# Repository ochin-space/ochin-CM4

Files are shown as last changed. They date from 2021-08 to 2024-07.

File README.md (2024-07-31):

ochin_CM4
# ochin_CM4
The öchìn CM4 it’s a tiny carrier board for the Raspberry Pi Compute Module  It is designed for applications where a powerful machine with low consumption and small dimensions is required. The small form factor makes it interesting for all those applications where the space available is not much and containing the weight is important, such as in robotics, home automation and IOT.
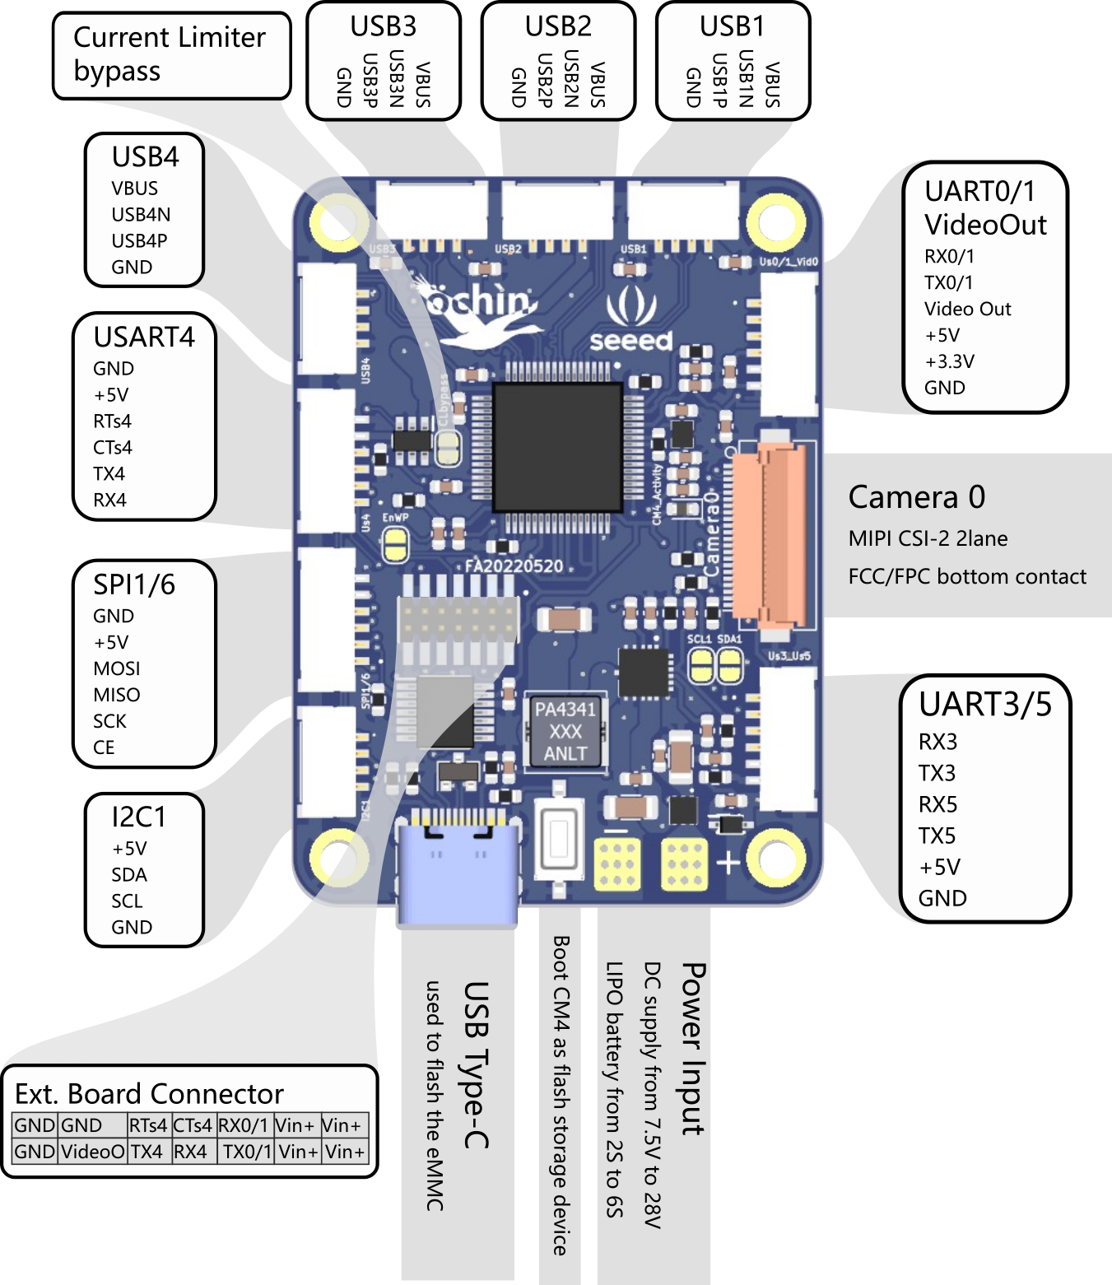
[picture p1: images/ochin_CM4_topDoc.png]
ochin_CM4

The board is compatible with all Raspberry Pi CM4 modules equipped with eMMC. Depending on your needs, you can select a CM4 module with an SDRAM starting from 1GB up to 8GB and the eMMC from 8GB up to 32GB, with or without the Wi-Fi / BT4 connection.

Key features of the Raspberry Pi CM4 available on öchìn are as follows:
* Broadcom BCM2711, Quad core Cortex-A72 (ARM v8) 64-bit SoC @ 1.5GHz
* Small Footprint 55mm × 40mm × 4.7mm module
* H.265 (HEVC) (up to 4Kp60 decode), H.264 (up to 1080p60 decode, 1080p30 encode)
* OpenGL ES 3.0 graphics
* Options for 1GB, 2GB, 4GB or 8GB LPDDR4-3200 SDRAM with ECC
* Options for 8GB, 16GB, or 32GB eMMC Flash
o Peak eMMC bandwidth 100MBytes/s
o 2.4 GHz, 5.0 GHz IEEE 802.11 b/g/n/ac wireless
o Bluetooth 5.0, BLE
o On board electronic switch to select between PCB trace or external antenna
* 1×USB 2.0 port (highspeed)
* MIPI CSI-2:
o 1×2-lane MIPI CSI camera port, 1×4-lane MIPI CSI camera port
* 1×USART, 3×UART, 1×I2C port, 1×SPI port, Analog Video Output

In this repository you can find the manual of the board, a quick start guide for flashing the CM4 module and a guide with some tips on how to make the connections to the ochin board. 

It is important to read them both before turning on the ochin_CM4 board, to know its characteristics and above all the sequence in which the signals are present on the connectors.

# Community

Feel free to join the öchìn CM4 [Discord](https://discord.gg/Uj9XfSwn) group with members helping each other.

# Where to buy the ochin_CM4 boards
The ochin_CM4 boards are manufactured and sold by Seeedstudio. You can purchase ochin_CM4 boards from Seeedstudio's marketplace, https://www.seeedstudio.com or from Seeedstudio's business partners (Digikey, Mouser, RS components and many others).

# License Notice for This GitHub Repository

This GitHub repository contains various resources that are subject to specific licenses. Please note the following information regarding the applicable licenses:

* Documentation, Manuals, PDF Schematics, scripts and Other Textual Content: All textual documents present in this repository, including manuals, schematics, and documentation, are released under the GNU Free Documentation License (GFDL).

* Hardware (KiCad Sources, Gerber Files, Assembly Files, etc.): The hardware-related items, including but not limited to KiCad sources, Gerber files, and assembly files, are subject to a proprietary license. This means that these resources are not released as open source and their use is governed by the terms specified in the accompanying documentation or separate terms of use provided.

Please respect the conditions of both licenses when using and distributing the materials in this repository.

For any questions or clarifications regarding the licenses, feel free to contact us.

# Important!!!

The ochin_CM4 board must be used with a Raspberry Pi CM4 module with eMMC (the lite version is not good), there is no slot for the microsd card onboard. The reasons for this choice are explained in the manual and concern the optimization of spaces and the efficiency of the internal flash.

Print and use the extractor for the CM4 module if you don't want to break the mezzanines, you can find the .stl in the "3d/Covers turrets and extractors" section of this repository.

Take a look at the "öchìn CM4 - Wiring and Suggestions.pdf" before power the board on, it may save your time and your devices.

Never trust the color code of the GHS cables, the sequence in which commercial GHS cables are assembled is often random and does not reflect the sequence of the signals present in the connectors of the ochin_CM4 board.

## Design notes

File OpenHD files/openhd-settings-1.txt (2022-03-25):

#!/bin/bash
#
# ======================================================================================
#    <BASIC RF/VIDEO LINK CONFIGURATION>
# ======================================================================================

# >>>>>>>>>>[FREQUENCY FOR OPEN.HD]-- in MHz (See full Frequency List Below)
# By default the frequency will be chosen automatically for the hardware you have connected to your ground/air pi,
# but if you want to set a frequency manually, make sure it is supported by your hardware. Atheros cards are 2.4Ghz only
# and Realtek 8812/14 cards are only stable on 5.8Ghz. Frequencies are listed at the bottom of this file
FREQ=5320

# >>>>>>>>>>[DATARATE] Lower settings yield higher range and vice versa.  
# Below are the datarate settings for Legacy B/G and MCS "N" modes. 
DATARATE=3

# 1 - 5.5   =    802.11b         1 - 6.5   =     MCS 0
# 2 - 11    =    802.11b         2 - 13    =     MCS 1
# 3 - 12    =    802.11g         3 - 13    =     MCS 1
# 4 - 19.5  =    802.11n         4 - 19.5  =     MCS 2
# 5 - 24    =    802.11g         5 - 26    =     MCS 3           
# 6 - 36    =    802.11g         6 - 39    =     MCS 4

# # >>>>>>>>>>[MCS ; Space Time Block Coding ; Low Density Parity Check]
# Only tested MCS+STBC+LDPC with RTL8812AU cards. MCS=Y only should work with Atheros cards when STBC/LDPC=N 
UseMCS=N
UseSTBC=N
UseLDPC=N

# # >>>>>>>>>>[IP/USB CAMERA SECONDARY DATA RATES]
# Applied only to 8812AU with 2nd IP/USB cam, all other setups, ignore! Ath9k will ignore secondary camera datarate and use DATARATE=
# 0=6.5Mbit (BPSK 1\2),		1=13Mbit (QPSK 1\2)
# 2= 19.5MBit (QPSK 3/4), 	3=26Mbit (16-QAM 1\2)
DATARATE_SECONDARY_8812AU=2

# >>>>>>>>>>[TXPOWER-AIR/GROUND]-- For Atheros AR9271 or RTL8812/14AU Cards ONLY
TxPowerAir=58
TxPowerGround=58

# >>>>>>>>>>[TXPOWER-RALINK]-- (Not confirmed Working]
TXPOWER=2000

# >>>>>>>>>>[FEC (FORWARD ERROR CORRECTION)]-- (8/4/1024 default) 
# *For higher bitrate and range, you can reduce FEC to "2" for example by setting (10/2/1024)
# max. blocklength Ralink = 2278, Atheros = 1550
# min. sensible blocklength ~ 700
VIDEO_BLOCKS=8
VIDEO_FECS=4
VIDEO_BLOCKLENGTH=1024

#Secondary camera (IP\USB)
VIDEO_BLOCKS_SECONDARY=8
VIDEO_FECS_SECONDARY=4

# >>>>>>>>>>[DEBUGGING OR SSH]--
# Set this to "Y" to enable collection of extra debug logs or to allow SSH. If you experience anyways
# issues. "Y" also turns on the display for the airpi
DEBUG=N

# >>>>>>>>>>[DISABLE SCREEN MESSAGES]--
# Set this to "Y" to disable text messages about Display and Wifi card setup etc.
QUIET=N

# >>>>>>>>>>[SCREENSHOTS]--
# Set to "Y" to enable periodic screenshots every 10 seconds
ENABLE_SCREENSHOTS=N

# >>>>>>>>>>[DISABLE OSD]--
# Set to "Y" to enable ground OSD. set "N" to only display video. 
DISPLAY_OSD=Y

# set to "Y" to use the QOpenHD app instead of the original OSD
ENABLE_QOPENHD=N

# >>>>>>>>>>[5/10/20Mhz BANDWIDTH SETTINGS]--Default 20mhz
# !!!!!!! ATHEROS CARDS ONLY  !!!!!!!!!!!!!!!!!!!!!
# Users can choose between 20mhz, 10mhz or 5mhz bandwidth at the expense of 1/4 or 1/2 of total available 
# Datarate/Bitrate. Range can be increased significantly with 5/10mhz "Narrowband".
# ***Default @ 20mhz compatible with all Wireless cards. 5/10mhz Bandwidth options will result in
# Bandwidth:5, 10 or 20.
Bandwidth=20

# ======================================================================================
#                            <VIDEO/CAMERA CONFIGURATION>
# ======================================================================================

# >>>>>>>>>>[VIDEO BITRATE]-- "auto" recommended
# Air Pi reads available bandwidth to determine bitrate.
# 
# Set to a fixed value to disable automatic measuring 
# 
# Note: the unit for this setting is megabits, not kilobits or bits!
# For 4.5mbit, set to 4.5
VIDEO_BITRATE=auto

# >>>>>>>>>>[BITRATE PERCENTAGE]-- "65 default"
# Depending on channel utilization by other wifi networks you may need to set
# this to a lower value like 60% to avoid a delayed video stream.
# On free channels you may set this to a higher value like 75% to get a higher
# bitrate and thus image quality.
BITRATE_PERCENT=50

# >>>>>>>>>>[CAMERA RESOLUTION]--
# V1 cam: 1280x720: 30fps, 48fps. 1920x1080: 30fps
# V2 cam: 1280x720: 30fps, 48fps, 59.9fps. 1640x922: 30fps, 40fps. 1920x1080: 30fps
WIDTH=1280
HEIGHT=720

# >>>>>>>>>>[CAMERA FPS]--"48 default"
# Choose between 30, 40, 48, 59.9, values above 60 are experimental
FPS=30

# >>>>>>>>>>[KEYFRAME RATE]-- 
# ***This is how often a "fresh-new" video frame is transmitted***
# Lower values mean faster glitch-recovery, but also lower video quality.
# With fps=48 and keyframerate=5, glitches will stay visible for around 100ms in worst case.
# You can set this higher or lower according to your needs. Minimum value is 2.
KEYFRAMERATE=10
#
# >>>>>>>>>>[RASPIVID CAMERA SETTINGS]--
# There are dozens of paramaters, see the RPI forum for all settings.
EXTRAPARAMS="-cd H264 -n -fl -ih -pf high -if both -ex sports -mm average -awb horizon"
# UNCOMMENT, AND USE THESE CAMERA SETTINGS FOR THE B101 OR SIMILAR HDMI-CSI ADAPTER
#EXTRAPARAMS="-cd H264 -n -fl -ih -pf high -if both"

# >>>>>>>>>>[SAVE VIDEO-RAMdisk/Memory]--Set to "memory" to use RAMdisk for temporary video/screenshot/telemetry 
# storage recording time to ~12-14 minutes, but is the safe way. If you need longer recording times, use "sdcard", to 
# use the sdcard as the temporary video storage. Keep in mind though, that this might introduce video stutter and/or bad blocks. 
# you can also disable recording entirely by setting VIDEO_TMP=none
VIDEO_TMP=memory

# >>>>>>>>>>[Use openhdvid instead of raspivid]
# Raspivid is the default and stable option, openhdvid is a new replacement for it that will allow live camera
# parameter changes and other enhancements. It is not well tested yet.
ENABLE_OPENHDVID=N

# >>>>>>>>>>[Use new raspberry pi camera AWB algorithm]
# Buster only (strech doesn't have new enough firmware for it)
# This option is here because the new AWB algorithm can cause color tint in certain cases, we're
# disabling it to use the old one by default. The advantage of the newer one is it doesn't shift as
# rapidly when the scene changes.
ENABLE_NEW_PI_AWB=N

# ======================================================================================
#                   <GROUND STATION/PC/PHONE/TABLET INTERFACE CONFIG>
# ======================================================================================

# >>>>>>>>>>[HOTSPOT SOURCE]-- **THE EXTERNAL HOTSPOT IS CURRENTLY BROKEN, DON'T USE**
# Set "internal" or MAC address of EXTERNAL wifi card
WIFI_HOTSPOT_NIC=internal

# >>>>>>>>>>[HOTSPOT MODE]-- Default SSID is "Openhd" Password "wifiopenhd"
# ***USE WITH QGC-PHONE, OPENHD APP, MISSION PLANNER OR HID/RC APP***
# Set "auto" (default) with Pi3b+ as GroundPi (it has 2.4/5ghz internal hotspot) OR Pi3b/2b video is 5.8ghz 
# and internal hotspot is 2.4ghz. For 2.4ghz hotspot and 2.4ghz video must be manually set at your own risk!
# Set "Y" to enable Hotspot and you (manually) set the band & ch below. 
# Set to "N" for no wifi hotspot (Recommended If NOT using Pi3b+ & 2.4ghz for video as it could # interfere.
WIFI_HOTSPOT=N

# >>>>>>>>>>[HOTSPOT BAND/CHANNEL_MANUAL CONFIG]
# NOTE with WIFI_HOTSPOT=auto your setting here will be over written.
# Set to "g" for 2.4ghz , "a" for 5.8ghz, 
# Channels 1-11 for 2.4Ghz, 
# Channels 36,40,44,48,52,56,60,64 for 5Ghz
HOTSPOT_BAND=a
HOTSPOT_CHANNEL=36
# Set to number of seconds you wany hotspot to shutdown. Default is "0", run forever
HOTSPOT_TIMEOUT=0
# hotspot transmit power in units of mBm, so 100 corresponds to 1dBm
# to set full power, use HOTSPOT_TXPOWER=3100
HOTSPOT_TXPOWER=3100

# >>>>>>>>>>[ETHERNET HOTSPOT]--*Only used for PC/Mission Planner Ethernet connection
# Set this to "Y" to enable Ethernet hotspot. This will forward the received video and 
# telemetry to another PC.
ETHERNET_HOTSPOT=N

# >>>>>>>>>>[FORWARD RTP/RAW h.264 VIDEO TO PC/PHONE]
# Set this to "raw" to forward a raw h264 stream to 2nd display devices (for QGC/FPV_VR app)
# Set to "rtp" to forward RTP h264 stream 
FORWARD_STREAM=rtp

# >>>>>>>>>>[UDP PORT SETUP]--
# UDP port to send video stream to, set to 5000 for FPV_VR app or 5600 for Mission Planner/QGC
VIDEO_UDP_PORT=5600
# *EXPERIMENTAL* Secondary IP/USB Camera UDP Port (DON'T CHANGE)
VIDEO_UDP_PORT2=5601

# ======================================================================================
#                     <TELEMETRY/USB RC CONFIGURATION>
# ======================================================================================

# >>>>>>>>>>[CTS PROTECTION]--Use in areas with other wifi networks or Interference
# Set "Y" in conjunction with ATHEROS "Range" RC
# Set "auto" for automatic detection. 
# Set "N" to disable.
CTS_PROTECTION=N

# >>>>>>>>>>[USB RC RANGE OR ENCRYPTION]-- 
# For Atheros AND RTL8812AU Cards use "Range".
# For any other cards use "Encryption" + CTS=N (NOT TESTED VERY MUCH)
# ***"Range" Uses the original EZ-wifibroadcast "joystick" code. This setting should provide better range. 

# ***"Encryption" Is a more secure means of RC uplink and works with any wifi cards but may
# Result in higher packet loss at longer ranges.
EncryptionOrRange=Range

# >>>>>>>>>>[RC JOYSTICK MODE OVER OPEN.HD SETTINGS]
# Set this to "mavlink" to enable R/C over Open.HD using mavlink protocol or "msp" for MSP
# protocol.
# Set to "sumd" for Graupner SUMD, "ibus" for Flysky IBUS, "srxl" for Multiplex SRXL/XBUS
# Mode B. Set to "disabled" to disable
# **See joyconfig.txt for other settings, default settings work for Taranis in USB.
RC=ibus

# >>>>>>>>>>[DEDICATED WIFI-CARD UPLINK/RC MAC ADDR.]-- If different types of Ground wifi cards are used.
# Set this if you have 1 High-Power ground card plus 1 or more lower power cards so that
# all uplink is sent using the high-power card. Otherwise, leave "0" and RC/Uplink will
# be automatically selected based on RSSI signal. 
# ***Also Set for Bandwidth Switcher Function (Below)***
#Ground RX card Primary
PrimaryCardMAC=0

# >>>>>>>>>>[TELEMETRY WBC/OTHER]--
# wbc = use wifibroadcast as telemetry up/downlink
# external = use external means as telemetry up/downlink (LRS or 3DR dongles)
# if set to external, set serialport to which LRS or 3DR dongle is connected
# both on ground and air pi
TELEMETRY_TRANSMISSION=wbc

# >>>>>>>>>>[TELEMETRY UPLINK]--
# Set to "disabled" or "mavlink" for Mavlink (QGC, Missionplanner, etc.)
TELEMETRY_UPLINK=mavlink

# >>>>>>>>>>[USB OPENHD-RC SERIAL PORT/BAUDRATE]--Serial Port Settings between Air Pi & Flight Controller.
# Serial port and baudrate (19200 is minimum) 
# Set this to "/dev/serial0" for Pi onboard UART serial port or "/dev/ttyUSB0" for FTDI adapter. 
FC_RC_SERIALPORT=/dev/serial0
FC_RC_BAUDRATE=115200

# >>>>>>>>>>[OPENHD-FC SERIAL PORT/BAUDRATE]-- Air Pi and Flight Controller 
# *Should be the same as FC_RC_BAUDRATE 
FC_TELEMETRY_SERIALPORT=/dev/serial0
FC_TELEMETRY_BAUDRATE=115200

# >>>>>>>>>>[EXTERNAL DEVICE SERIAL PORT BAUDRATE]--Serial port settings if using TELEMETRY_TRANSMISSION=external
EXTERNAL_TELEMETRY_SERIALPORT_GROUND=/dev/serial0
EXTERNAL_TELEMETRY_SERIALPORT_GROUND_BAUDRATE=57600

# >>>>>>>>>>[GROUND SERIAL PORT OUT ENABLE?]--Set to "Y" to enable output of telemetry to serialport on ground Pi
# (for antenna tracker etc.)
ENABLE_SERIAL_TELEMETRY_OUTPUT=N

# >>>>>>>>>>[GROUND SERIAL PORT/BAUDRATE OUT]-- 
# Used for ground Pi telemetry output if TELEMETRY_OUTPUT=Y
TELEMETRY_OUTPUT_SERIALPORT_GROUND=/dev/serial0
TELEMETRY_OUTPUT_SERIALPORT_GROUND_BAUDRATE=57600

# >>>>>>>>>>[Filter Mavlink 2 telemetry for slow trackers]
# This prevents some antenna trackers from being overloaded by extra mavlink messages.
# You should not enable this if you do not use Mavlink or if you are not using an antenna tracker.
TELEMETRY_OUTPUT_SERIALPORT_GROUND_FILTER=N

#  ======================================================================================
#                      <ADVANCED/ADDITIONAL HARDWARE SETTINGS>
#  ======================================================================================

# >>>>>>>>>>[ARDUCAM V2.0 OR V2.1 MULTI-CAMERA ADAPTER]-- 
# This Camera Switcher feature must be used with the Arducam 4 camera Raspberry Pi multiplexer.  
# If no camera switcher is detected, feature is automatically disabled.  if used, simply assign
# desired RC Channel and pwm values for each camera.  Default settings are for 2 Cams A&B.
IsCamera1Enabled=1
IsCamera2Enabled=1
IsCamera3Enabled=1
IsCamera4Enabled=0
#
DefaultCameraId=1
ChannelToListen=16
#
Camera1ValueMin=700
Camera1ValueMax=1400
#
Camera2ValueMin=1450
Camera2ValueMax=1800
#
Camera3ValueMin=1850
Camera3ValueMax=2200
#
Camera4ValueMin=2250
Camera4ValueMax=2500

# >>>>>>>>>>[AUDIO OVER OPENHD-USB-MICROPHONE]--
# Aability to transmit audio with Linux USB-Microphone and output over analog, HDMI or set to auto. 
# *USE ONLY WITH PI2 or PI3/3b+ Air.
# 0 Auto, 1 Analog, 2 HDMI
DefaultAudioOut=0
# Audio Enabled? "0"= Off "1"=ON
IsAudioTransferEnabled=0
# Audio Mic/Speaker Gains
MicBoost=75
SpeakersLevel=75

# >>>>>>>>>>[VEYE-IMX290 CAMERA MODULE & SETTINGS]--
EXTRAPARAMS_IMX290="-cd H264 -n -fl -ih -pf high -if both"
IMX290_videoformat=PAL

# 0x00 Back Light Mode OFF
# 0x01 Back Light Mode LOW
# 0x02 Back Light Mode HIGH
# 0x03 DOL WDR Enable
IMX290_wdrmode=0x03

# 0x00 Normal
# 0x01 Mirror
# 0x02 V-Flip
# 0x03 Mirror And V-Flip(180 Degree Rotate)
IMX290_mirrormode=0x00

# This is a complicated setting, see here: http://wiki.veye.cc/index.php/VEYE-MIPI-290/327_i2c
IMX290_denoise=0x00

# 0x00 means fixed framerate, up to 0x11 will allow the camera to adjust framerate to increase exposure, which 
# may not be desirable for FPV
IMX290_lowlight=0x00

# agc indicated max gain of AE mode
# Range 0x00 to 0x0F
IMX290_agc=0x00

# AE Target Brightness
# Range 0x00 to 0x64
IMX290_brightness=0x32

# AE adjust speed, p1 is agc speed, p2 is shutter speed，Slow to Fast: [0, 0x64]
# Range 0x00 to 0x64
IMX290_aespeed1=0x32
IMX290_aespeed2=0x32

# Range 0x00 to 0xFF
IMX290_contrast=0x80

# Range 0x00 to 0x64
IMX290_saturation=0x32

# 0x0 disables, 0x1 enables
IMX290_sharppen1=0x1

# Sets the sharpen strength, sharppen1 must be enabled
# Range [0x0-0xA]
IMX290_sharppen2=0xA

# The overall AE target value in WDR mode.
# Takes effect in WDR mode. range: [0-0xFF]
IMX290_wdrtargetbr=0x80

# The auto exposure target value of the bright area in WDR mode.
# Takes effect in WDR mode. range: [0-0xFF]
IMX290_wdrbtargetbr=0x80

# Used to flip/mirror the IMX307 camera, separate setting from IMX290 because they don't handle it the same way
# 0: normal, 1: flip, 2: mirror, 3: flip+mirror. 
# Note that the IMX307 configuration system seems to expect numbers like 0, not 0x00 like imx290 mirrormode
IMX307_imagedir=0

# ======================================================================================
#                    <DEVELOPER-ENHANCEMENTS IN PROGRESS OPTIONS>
# ======================================================================================

# >>>>>>>>>>[MIRROR DSI AND HDMI DISPLAY]--See wiki for how-to
MirrorDSI_To_HDMI=Y

# >>>>>>>>>>[MSP TELEMETRY STUFF]--not supported yet, do not change
FC_MSP_SERIALPORT=/dev/ttyUSB0
FC_MSP_BAUDRATE=115200

# >>>>>>>>>>[ADJUST UPLINK DATARATE]--
# *11Mbps is the default 802.11 data rate, lower rates do not appear to improve any range/quality because
# the "packet size" of the RC/Uplink data is so small to begin with that 1, 5.5, 6 Mbps makes no difference.
UplinkSpeed=11

# >>>>>>>>>>[FEATURE BANDWIDTH SWITCHER] Allows users to remotely switch between 5/10/20 mhz bandwidth. simply assign RC 
# Channel and pwm values for each setting (>2 selectable settings must be used on Axis RC channels 1-8)
# **ONLY TESTED ON THE GROUND SO FAR. IN ORDER FOR THE BANDWIDTH TO SWITCH, THERE MUST BE A GOOD LINK BETWEEN ALL AIR AND GROUND WIFI CARDS. 
# **RC bandwidth switcher is only tested with pi2/3 air.  if using RPI zero it is recommended to disable the switcher and instead set a 
# fixed desired bandwidth prior to flight.  
# **YOU MUST ALSO DEFINE THE MAC ADDRESSES OF YOUR GROUND ath9k Atheros cards for use with the RC bandwidth Switcher.  
# MAKE SURE THAT YOUR MOST POWERFUL GROUND RECEIVER CARD MAC ADDRESS IS SET AS THE "PRIMARY RX/TX".
# IsBandSwicherEnabled "0"=disabled "1"= enabled 
# *Must have "Master-Mac address set above". 
IsBandSwicherEnabled=0
ChannelToListen2=8
Band5Below=1200
Band10ValueMin=1200
Band10ValueMax=1650
Band20After=1650

# >>>>>>>>>>[RELAY OPEN.HD}--
# DO NOT USE. BROKEN.
# Set this to "Y" to enable Open.HD relay mode. Will forward the received video and teleme stream.
# to another Open.HD RX.
RELAY=N
RELAY_NIC=112233445566
RELAY_FREQ=5220

# >>>>>>>>>>[CHANGE TMP VIDEO PARTITION TYPE]--
# VIDEO_FS set to "ext4" (Linux, which is recommended for performance) or "fat" (Windows)
VIDEO_FS=ext4

# >>>>>>>>>>[CHANGE TMP VIDEO PARTITION TYPE]--
# VIDEO_SAVE_FORMAT sets the container used when saving video to a USB stick on the ground station.
# You can choose any format that ffmpeg can handle, the default is still avi but mp4 is broadly compatible
# with most devices now as well. The default may change soon.
VIDEO_SAVE_FORMAT=mp4

# >>>>>>>>>>[AIRODUMP Y/N]--Set to "Y" to scan for wifi networks with airodump-ng before starting RX
AIRODUMP=N
# Number of seconds wifi scanner is shown. Minimum recommended scanning time is 25 seconds.
AIRODUMP_SECONDS=25

# >>>>>>>>>>[FEATURE: 2-WAY COMM APP]-- For Air/Ground settings with Open.HD APP.
# This enables or disables two-way communication between the open HD app and air/ground units.
# **Setting "2" disables AirPi remote settings (not needed anyways), 
# Primary benefit is to keep RPI zero CPU Usage down to a minimum with Atheros. Setting "1" Is helpful for quickly changing/testing
# settings on Air Side by immediately applying changes for comparison without the need for SmartSync. 
#Values "2"=Enables Ground Only, then uploads changes to air during SSync Boot (default) ; "1"=EnableAir/Ground Immediately save air changes through app...(Not recommended for regular usage)
RemoteSettingsEnabled=2

# >>>>>>>>>>[SmartSync Settings]--**SmartSync_StartupMode="0" means air/ground will boot quickly but can trigger SmartSync with CH2 movement or GPIO# 26 Cross Connected.
SmartSync_StartupMode=1
# RC Channel should default to middle (1500pwm position) to work properly
SmartSyncRC_Channel=2
# DO NOT CHANGE THE BELOW SMARTSYNC SETTINGS!
SmartSyncGround_Countdown=60
SmartSyncOFF_RC_Value=1700
SmartSyncStayON_RC_Value=1300
SmartSyncControlVia=joystick
# We strongly suggest leaving this on auto, but any frequency from the list at the bottom of this file will work.
# If you change this it MUST be a frequency that works on your wifi cards, and it MUST match on the ground and air 
# side or smartsync itself will not work
SmartSync_Frequency=auto

# ======================================================================================
#                    <DEVELOPER-ENHANCEMENTS IN PROGRESS OPTIONS>
# ======================================================================================

# >>>>>>>>>>[SECONDARY IP/USB CAMERA SETTINGS]--
# Values: No, IP, USB
SecondaryCamera=No

# >>>>>>>>>>[SECONDARY PIP CAMERA SWITCHER RC CHANNEL]--
# IP or USB secondary camera. To use "IsBandSwicherEnabled=1" must be enabled
# RC channel to switch 3 different modes:  (#Camera1ValueMin .. Camera3ValueMax - used )
#     Mode 1: LCD(HDMI) + android phone - RPi CSI camera
#     Mode 2: LCD(HDMI) - RPi CSI camera, android phone - IP or USB camera. Bitrate = bitrate / 2 (20MHz) ,4(10Mhz) ,8(5Mhz). IPCameraLowRes is used  
#     Mode 3: Adroid phone only -  IP or USB camera. IPCameraHiRes (20MHz) , or auto bitrate = initial-bitrate=\$1 USBCamera. (20MHz, 10Mhz /2, 5Mhz /4). 
#             (To use fixed: initial-bitrate=200000)
# Note: if set to 1-8, this will use one of the 8 RC axis from your transmitter. If set to 9-24, it will
# use 2 consecutive buttons on the transmitter as a sort of fake 3-way switch.
ChannelIPCamera=7

# >>>>>>>>>>[OPTIONAL FLIR-USB CAMERA DRIVER SETUP]--
# Values: Y N
LoadFlirDriver=N

# >>>>>>>>>>[OPTIONAL SEEK-USB CAMERA DRIVER SETUP]--
# Values: Y N
LoadSeekDriver=N
# You should change this in USBCamera as well if you need to change it at all
SeekFramerate=7
# This affects the colorization used for the thermal range, experiement to find the one you like
SeekColormap=1
SeekRotate=0
# Can also be seekpro
SeekModel=seek

# >>>>>>>>>>[IP/USB CAMERA PIPELINE OPTIONS]--*Uncomment corresponding per ip/usb camera type
#USBCamera="gst-launch-1.0 uvch264src device=/dev/video0 initial-bitrate=\$1 average-bitrate=\$1 iframe-period=1000 name=src auto-start=true src.vidsrc ! queue ! video/x-h264,width=1280,height=720,framerate=30/1 ! h264parse ! rtph264pay ! udpsink host=127.0.0.1 port=5600"

#IPCameraHiRes="gst-launch-1.0 rtspsrc location=\"rtsp://192.168.0.10:554/user=admin&password=&channel=1&stream=0.sdp\" latency=0 ! udpsink port=5600 host=127.0.0.1"
#IPCameraLowRes="gst-launch-1.0 rtspsrc location=\"rtsp://192.168.0.10:554/user=admin&password=&channel=1&stream=1.sdp\" latency=0 ! udpsink port=5600 host=127.0.0.1"

# >>>>>>>>>>[FLIR CAMERA PIPELINE OPTIONS]--
#FLIR HD (visible image) -  640 x 480 @ 9fps:
#USBCamera="gst-launch-1.0 v4l2src device=/dev/video2 ! video/x-raw,width=640,height=480,framerate=30/1 ! videoconvert ! v4l2h264enc  ! h264parse config-interval=3 ! rtph264pay ! udpsink host=127.0.0.1 port=5600"

#FLIR Thermal  - 160 x 128 @ 9fps:
#USBCamera="gst-launch-1.0 v4l2src device=/dev/video3 ! video/x-raw,width=160,height=128,framerate=30/1 ! videoconvert ! v4l2h264enc  ! h264parse config-interval=3 ! rtph264pay ! udpsink host=127.0.0.1 port=5600"

#Seek Thermal  - 206 x 156 @ 7fps:
#USBCamera="gst-launch-1.0 v4l2src device=/dev/video4 ! video/x-raw ! videoconvert ! v4l2h264enc  ! h264parse config-interval=3 ! rtph264pay ! udpsink host=127.0.0.1 port=5600"

#Seek Thermal Pro - 320 x 240 @ 15fps:
#USBCamera="gst-launch-1.0 v4l2src device=/dev/video4 ! video/x-raw ! videoconvert ! v4l2h264enc  ! h264parse config-interval=3 ! rtph264pay ! udpsink host=127.0.0.1 port=5600"

#Hti-301 thermal camera - 384 x 288 @ 25fps
#USBCamera="gst-launch-1.0 v4l2src device=/dev/video0 ! video/x-raw ! videocrop top=0 left=0 right=0 bottom=4 ! videoconvert ! v4l2h264enc  ! h264parse config-interval=3 ! rtph264pay mtu=1024 ! udpsink host=127.0.0.1 port=5600"

#gstreamer videotestsrc:
#USBCamera="gst-launch-1.0 videotestsrc ! video/x-raw,width=160,height=120,framerate=30/1 ! videoconvert ! v4l2h264enc  ! h264parse config-interval=3 ! rtph264pay ! udpsink host=127.0.0.1 port=5600"

# >>>>>>>>>>[Adjust channel value using other channel.]--
# That function let make 2 way toggle switch be 3 way switch using other 2 way toggle switch. May be used with IP\USB camera switch, etc...
# Values: 1-8
# In case if channel 0 is selected function disabled.
TrimChannel=0
# Action: 1 - add PWM to channel. 0 - extract PWM from channel
Action=1
# PWM value to add\extract: 1-900
PWMCount=202
# To trigger function PWM value must be above 1850. To return back lower 1700
ActivateChannel=0

# >>>>>>>>>>[LORA RADIO]--Under Development
# Values "0" or "1"
Lora=0

# >>>>>>>>>>[LTE]--Under Development
# Enable LTE. Y or N
LTE=N
# Zerotier network ID
ZT_NETWORK=1d71939404c3d2fd
# IP address of client (Zerotier managed IP on viewing device)
ZT_IP=172.26.128.187

# >>>>>>>>>>[Adjust LCD screen backlight using touchscreen]--
AdjustLCDBacklight=Y
# Time in seconds
AutoDimTime=30
# Values from 0 to 255, where 0 - off or 0%, 255 - or or 100%
AutoDimValue=255

# >>>>>>>>>> [TTY CONSOLE]-- View Output of GroundPi Consoles and Scripts
# set to "13" for a blank screen
TTY_CONSOLE=13

# Used to override the 802.11 frame type that will be used for telemetry, for testing purposes
FORCE_REALTEK_TELEMETRY_DATA_FRAME=N

# ======================================================================================
#                          FREQUENCY LIST AND OTHER Settings
# ======================================================================================

# [FREQUENCY AND ALTERNATIVE MULTI-CARD TRANSMISSION CONFIGURATION]
# Set to "Y" on the RX for auto-scanning. Frequency still has to be set on TX!
# Feature might be buggy or not work at all!
FREQSCAN=N

# [FREQUENCY LIST]
# {2.3-2.7Ghz}
# 2412, 2417, 2422, 2427, 2432, 2437, 2442, 2447, 2452, 2457, 2462, 2467, 2472, 2484 (Ralink and Atheros)
# 2312, 2317, 2322, 2327, 2332, 2337, 2342, 2347, 2352, 2357, 2362, 2367, 2372, 2377, 2382, 2387, 2392, 2397, 2402, 2407 (Atheros only)
# 2477, 2482, 2487, 2489, 2492, 2494, 2497, 2499, 2512, 2532, 2572, 2592, 2612, 2632, 2652, 2672, 2692, 2712 (Atheros only)
#
# {5Ghz)
# 5180, 5200, 5220, 5240
# 5260, 5280, 5300, 5320, 5500, 5520, 5540, 5560, 5580, 5600, 5620, 5640, 5660, 5680, 5700 *(DFS RADAR CHANNELS--MAY CAUSE PROBLEMS, RECOMMEND TO AVOID THESE).
# 5745, 5765, 5785, 5805, 5825
#
# ***(2.3Ghz and 2.5-2.7Ghz band only works with Atheros cards. Check your local regulations before transmitting)!
# Frequencies higher than 2512MHz work with Atheros, but with a lot lower transmit power and sensitivity and
# thus greatly reduced range. Only useable for short-range applications!
#
# Set this to "single" for single TX wifi card, for dual TX wifi cards set "dual".
# MAC addresses and frequency for the RX and TX wifi need to be set here when dual TX mode is enabled.
#
TXMODE=single
#
MAC_RX[0]=00c0ca91ee30
FREQ_RX[0]=2484
#
MAC_RX[1]=24050f953384
FREQ_RX[1]=2484
#
MAC_RX[2]=24050f953378
FREQ_RX[2]=2484
#
MAC_RX[3]=24050f953373
FREQ_RX[3]=2484
#
#
MAC_TX[0]=24050f953378
FREQ_TX[0]=5745
#
MAC_TX[1]=ec086b1c7834
FREQ_TX[1]=2472

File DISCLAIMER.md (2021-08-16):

# IMPORTANT NOTICE AND DISCLAIMER
-    Descriptions of circuits, software and other related information in this document are provided only to illustrate the operation of semiconductor products and application examples. You are fully responsible for the incorporation of these circuits, software, and information in the design of your equipment.  pernicious-flier assumes no responsibility for any losses incurred by you or third parties arising from the use of these circuits, software, or information.

-   pernicious-flier has used reasonable care in preparing the information in this document, but  pernicious-flier does not warrant that such information is error free.  pernicious-flier assumes no liability whatsoever for any damages incurred by you resulting from errors in or omissions from the information included herein.

-   pernicious-flier does not assume any liability for infringement of patents, copyrights, or other intellectual property rights of third parties by or arising from the use of  pernicious-flier projects or technical information described herein. No license, express, implied or otherwise, is granted hereby under any patents, copyrights or other intellectual property rights of  pernicious-flier or others.

-   You should not alter, modify, copy, or otherwise misappropriate any  pernicious-flier project, whether in whole or in part.  pernicious-flier assumes no responsibility for any losses incurred by you or third parties arising from such alteration, modification, copy or otherwise misappropriation of pernicious-flier projects.

-    pernicious-flier projects are neither intended nor authorized for use in products or systems that may pose a direct threat to human life or bodily injury (artificial life support devices or systems, surgical implantations etc.), or may cause serious property damages (nuclear reactor control systems, military equipment etc.). You must check the quality grade of each pernicious-flier project  before using it in a particular application. You may not use any  pernicious-flier projects for any application for which it is not intended.  pernicious-flier shall not be in any way liable for any damages or losses incurred by you or third parties arising from the use of any  pernicious-flier projects for which the product is not intended by Seeed Studio.

-   You should use the  pernicious-flier projects described herein within the range specified by  pernicious-flier, especially with respect to the maximum rating, operating supply voltage range, movement power voltage range, heat radiation characteristics, installation and other product characteristics.  pernicious-flier shall have no liability for malfunctions or damages arising out of the use of  pernicious-flier projects beyond such specified ranges.

-    Although  pernicious-flier endeavors to improve the quality and reliability of its projects, semiconductor products have specific characteristics such as the occurrence of failure at a certain rate and malfunctions under certain use conditions. Further,  pernicious-flier projects are not subject to radiation resistance design. Please be sure to implement safety measures to guard them against the possibility of physical injury, and injury or damage caused by fire in the event of the failure of a  pernicious-flier projects, such as safety design for hardware and software including but not limited to redundancy, fire control and malfunction prevention, appropriate treatment for aging degradation or any other appropriate measures. Because the evaluation of microcomputer software alone is very difficult, please evaluate the safety of the final products or systems manufactured by you.

-   Please use  pernicious-flier projects in compliance with all applicable laws and regulations that regulate the inclusion or use of controlled substances, including without limitation, the EU RoHS Directive.  pernicious-flier assumes no liability for damages or losses occurring as a result of your noncompliance with applicable laws and regulations.

-    pernicious-flier projects and technology may not be used for or incorporated into any products or systems whose manufacture, use, or sale is prohibited under any applicable domestic or foreign laws or regulations. You should not use  pernicious-flier projects or technology described in the board design files for any purpose relating to military applications or use by the military, including but not limited to the development of weapons of mass destruction. When exporting the  pernicious-flier projects or technology described in this document, you should comply with the applicable export control laws and regulations and follow the procedures required by such laws and regulations.

-   It is the responsibility of the user or distributor of pernicious-flier projects, who distributes, disposes of, or otherwise places the product with a third party, to notify such third party in advance of the contents and conditions set forth in this document,  pernicious-flier assumes no responsibility for any losses incurred by you or third parties as a result of unauthorized use of  pernicious-flier projects.

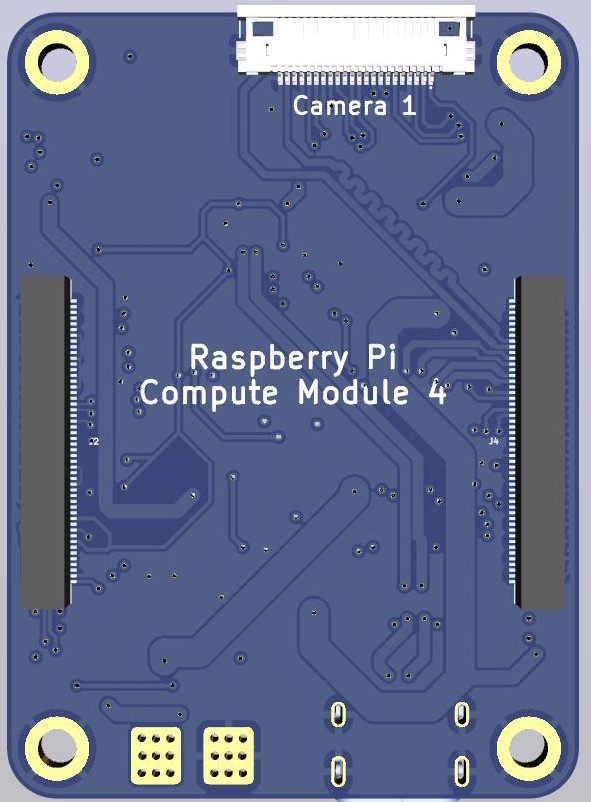
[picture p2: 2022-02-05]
images/Ochin_CM4_bot_.jpg

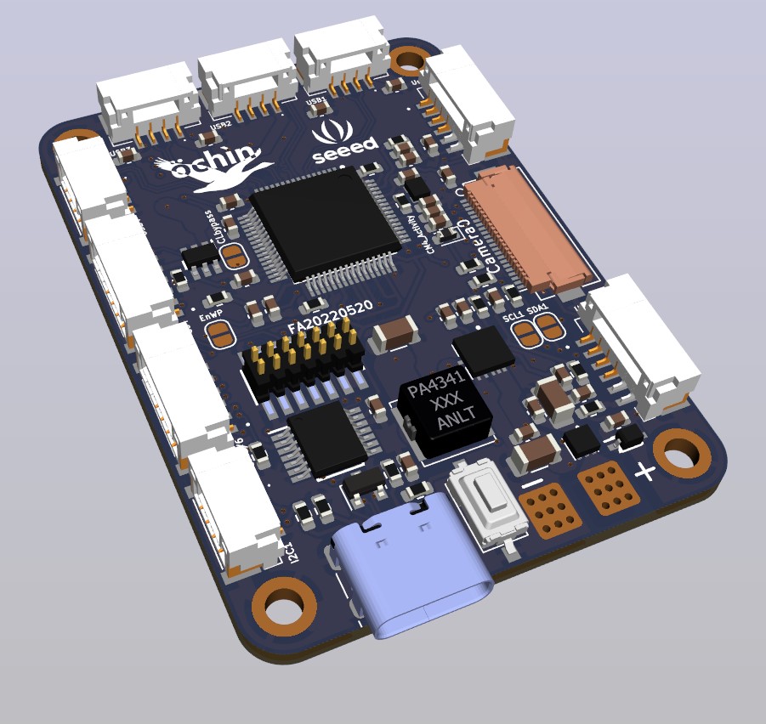
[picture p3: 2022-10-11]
images/Ochin_CM4_top_back.jpg

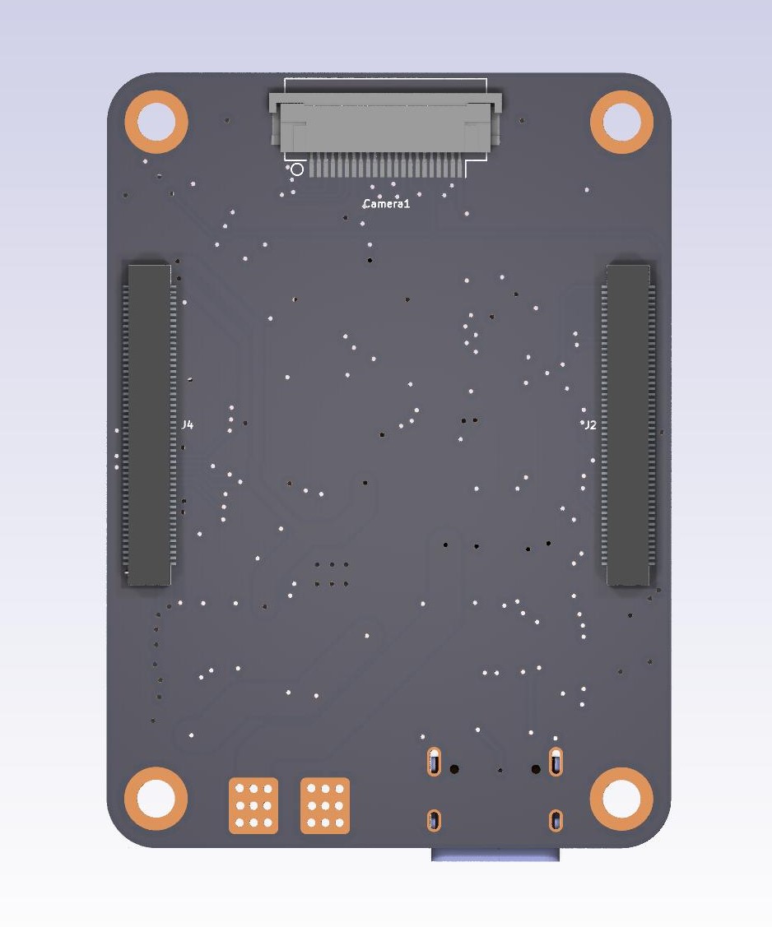
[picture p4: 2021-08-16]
images/OchinCM4_bot.jpg

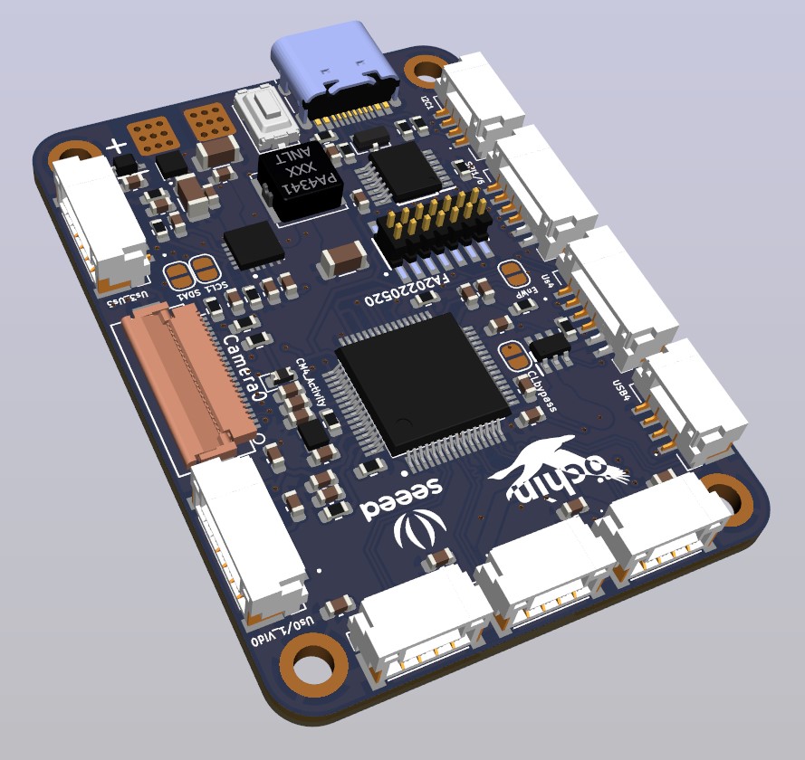
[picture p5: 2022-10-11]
images/Ochin_CM4_top_front.jpg

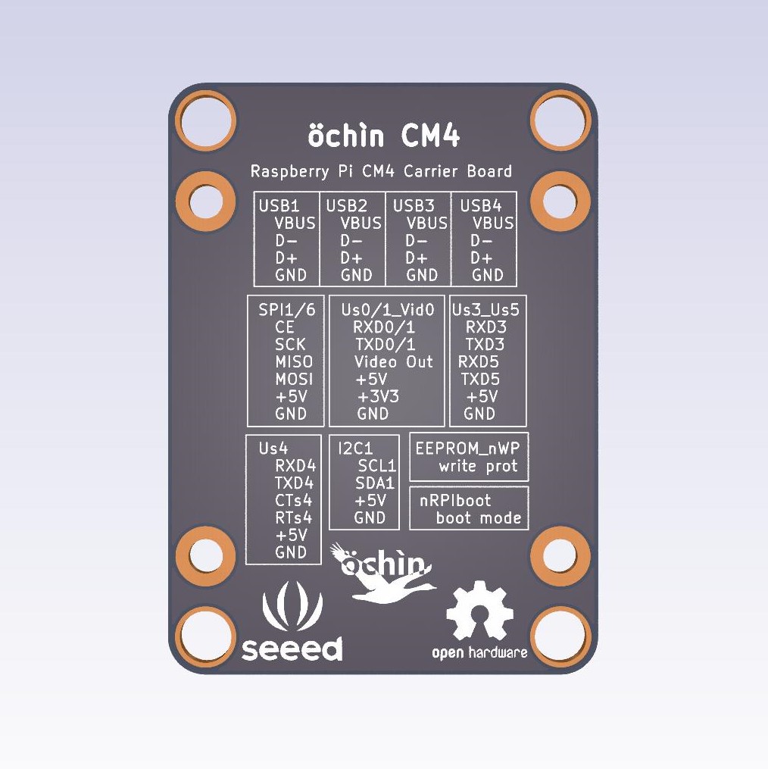
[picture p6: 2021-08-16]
images/Ochin_back.jpg

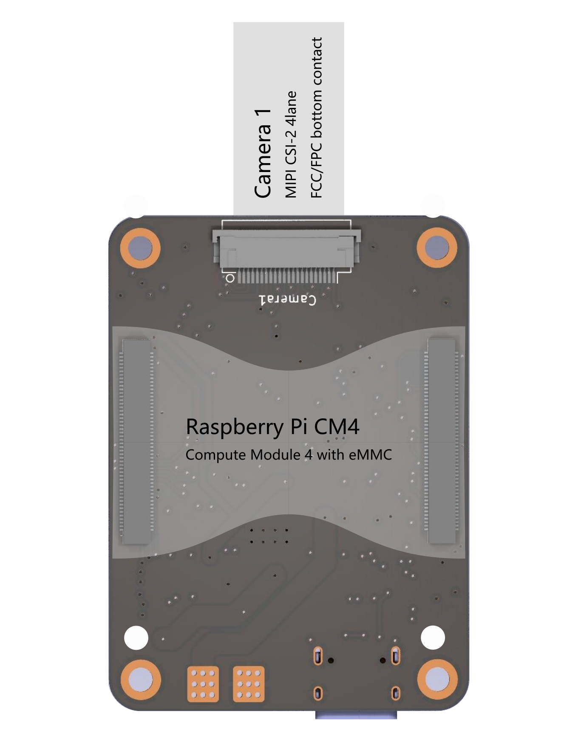
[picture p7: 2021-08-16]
images/ochin_CM4_botDoc.png

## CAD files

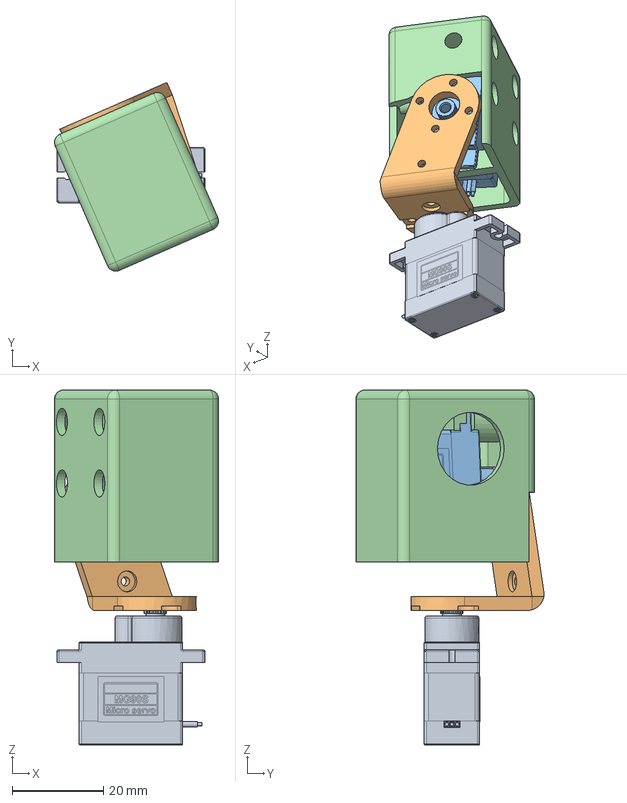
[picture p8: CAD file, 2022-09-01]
3d/camera microservo gimbal/camera_gimbal_assembly.FCStd
36.0 x 41.3 x 77.9 mm
Assembly SERVO1_001
camera_gimbal_pan_001
Assembly SERVO1_002
camera_gimbal_tilt_001

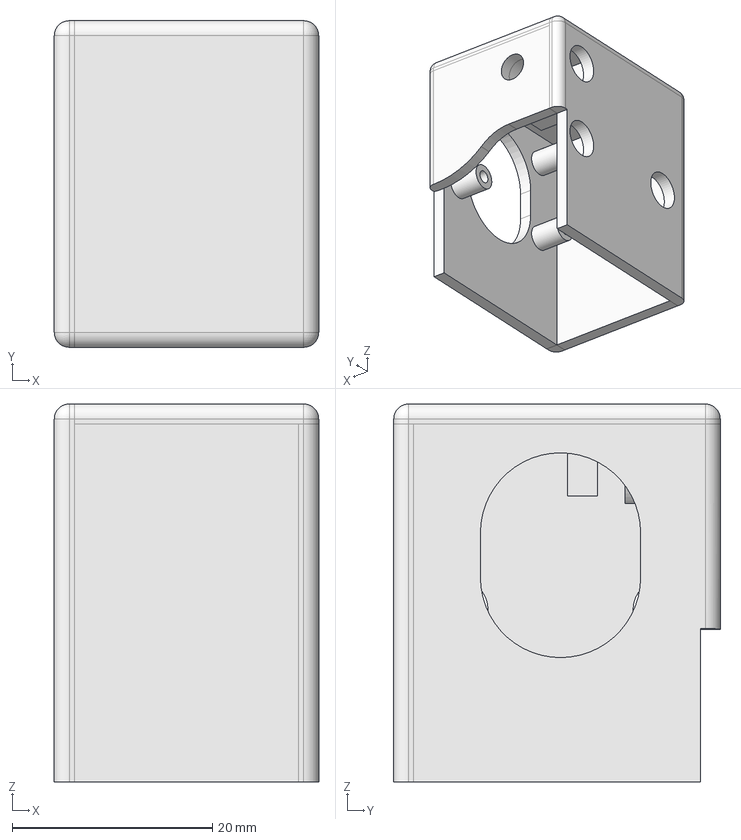
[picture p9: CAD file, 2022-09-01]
3d/camera microservo gimbal/camera_gimbal_tilt.FCStd
26.4 x 32.6 x 37.8 mm

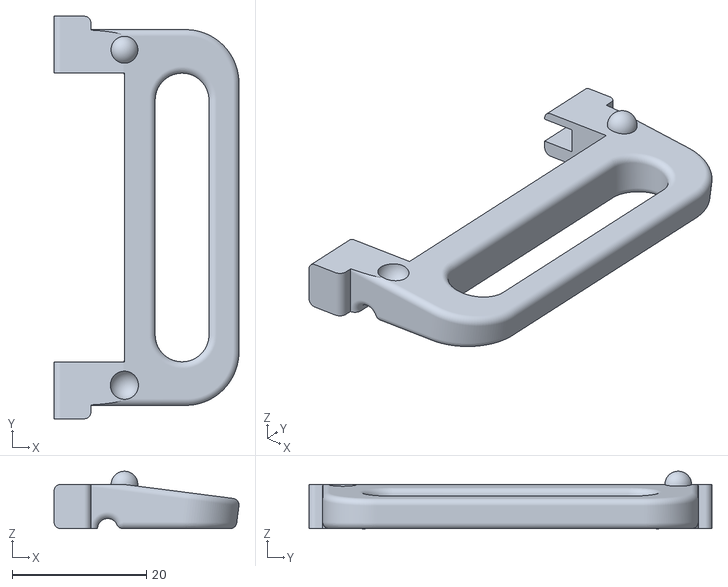
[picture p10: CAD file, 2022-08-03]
3d/Covers turrets and extractors/ochin_mount-extractor.stl
27.6 x 60.0 x 8.58

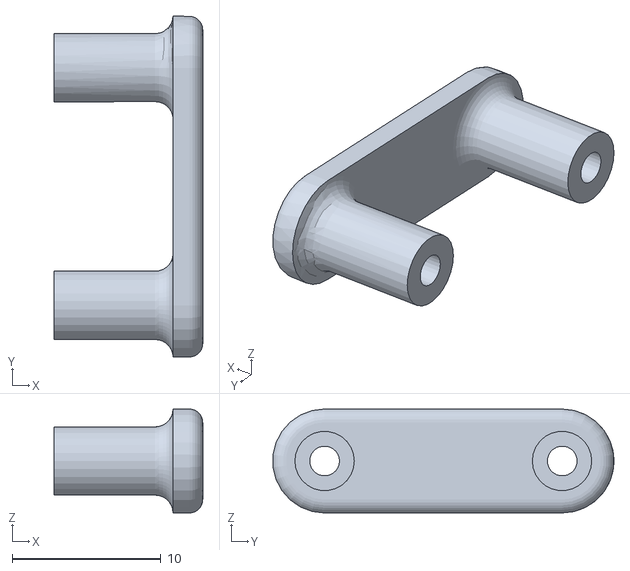
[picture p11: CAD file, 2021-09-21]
3d/EasyStar ii_IMX219_mount/EasyStar_camera_mount_bridge.stl
10.0 x 23.0 x 7.00

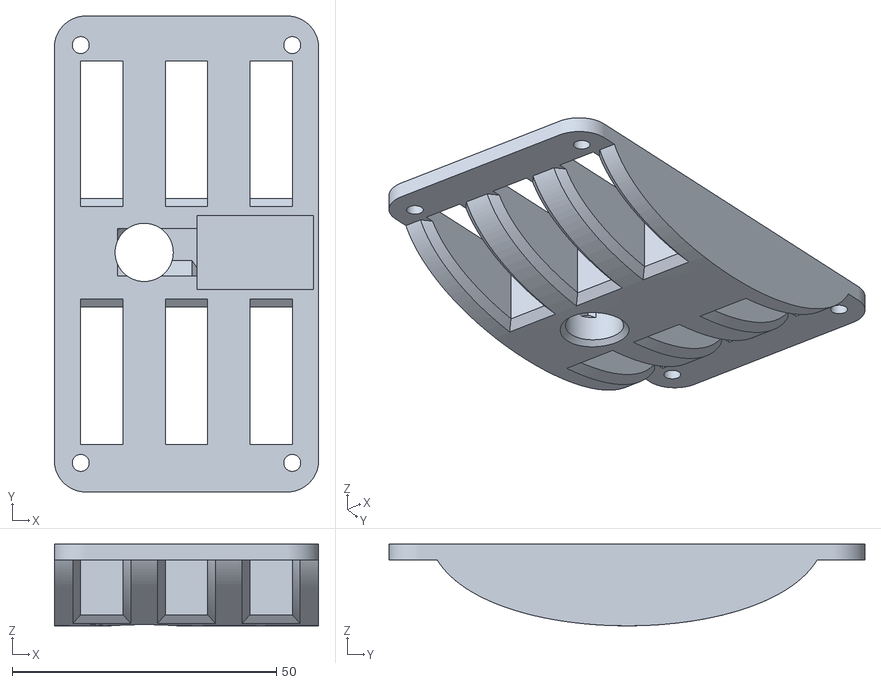
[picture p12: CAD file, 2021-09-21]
3d/ochin_cm4_plate_mount/ochin_cover+camera.stl
50.0 x 90.0 x 15.5

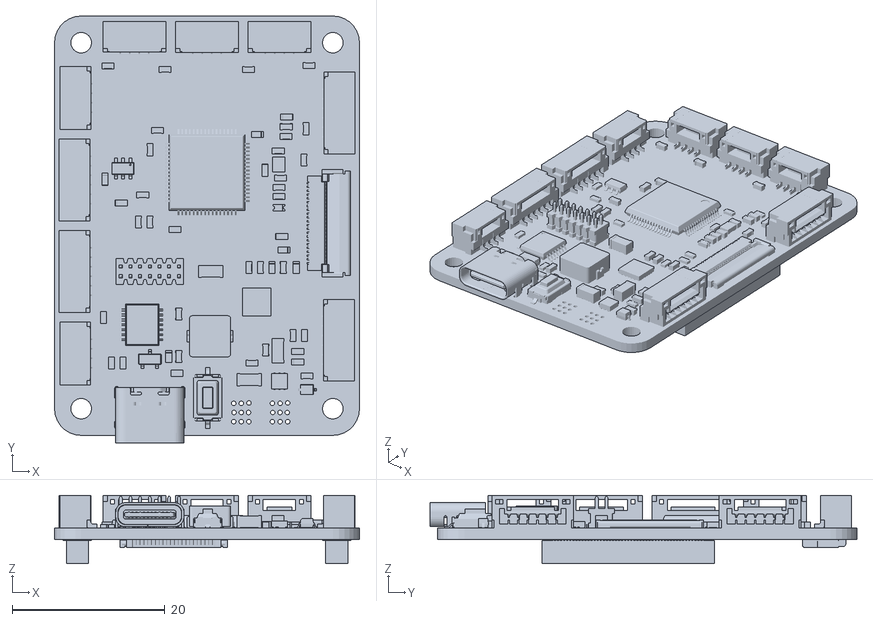
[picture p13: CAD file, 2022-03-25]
3d/opchin_cm4/ochin_CM4.stl
40.0 x 56.0 x 8.93

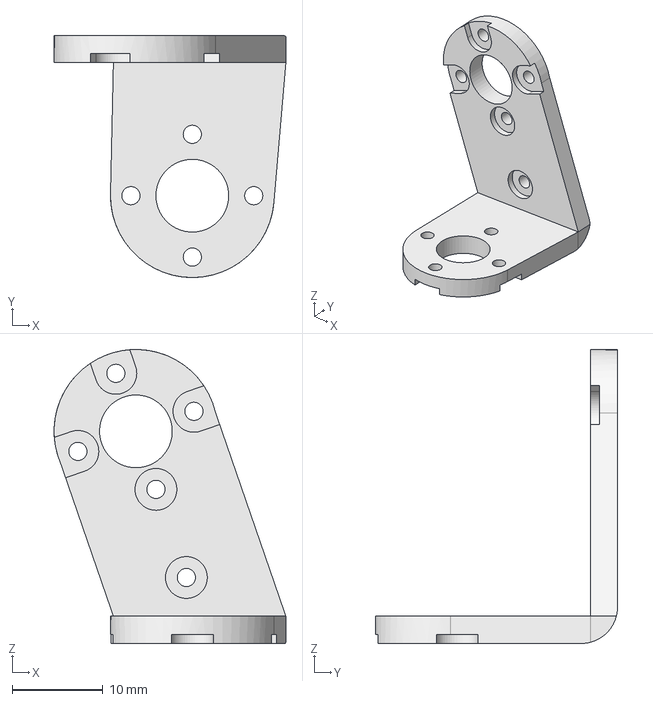
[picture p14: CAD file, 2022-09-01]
3d/camera microservo gimbal/camera_gimbal_pan.FCStd
25.5 x 26.6 x 32.3 mm

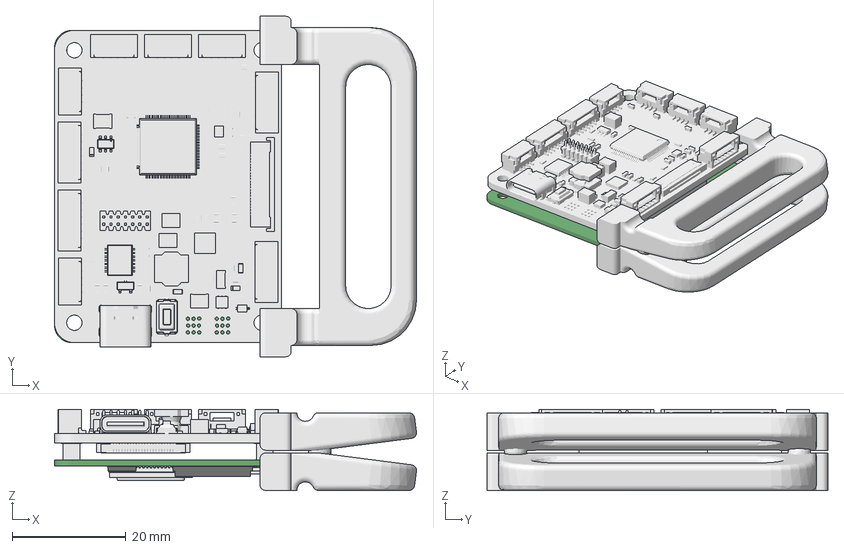
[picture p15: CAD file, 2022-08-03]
3d/Covers turrets and extractors/ochin_mount.FCStd
63.8 x 60.0 x 14.3 mm
PCB
BROADCOM_BCM2711
CONNDF40C-100DP-04V
CONNDF40C-100DP-04V (1)
MAXLINEAR_MXL7704-R
RM0_FOOTPRINT_V2
SAMSUNG_KLM4G1YE4C-B00X
SDRAM-LPDDR4-X32-D2-BGA200
extractor
extractor2
ochin_CM4-Ochin

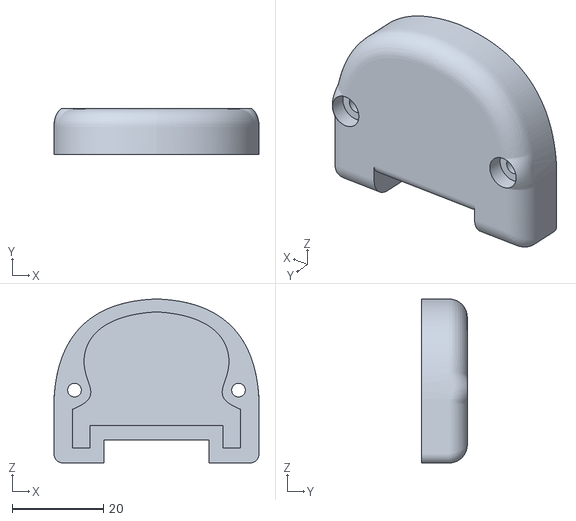
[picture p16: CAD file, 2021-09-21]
3d/EasyStar ii_IMX219_mount/EasyStar_camera_mount_cap.stl
45.0 x 10.0 x 36.0

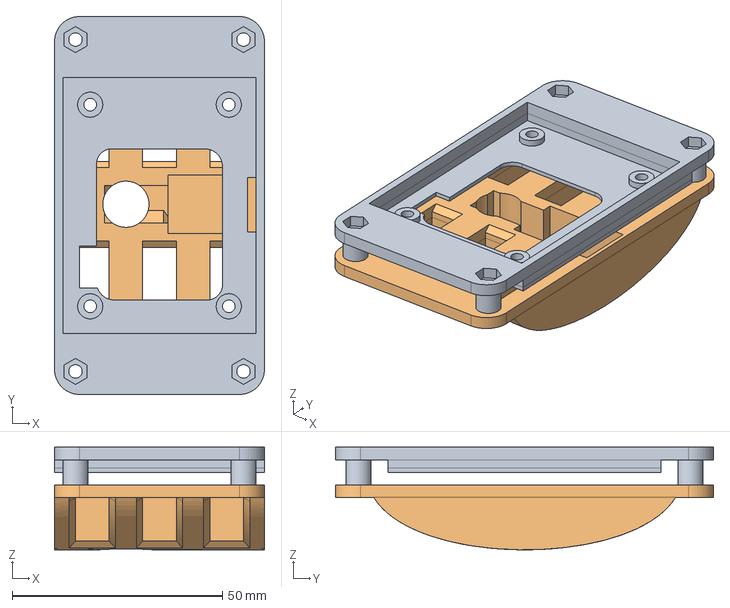
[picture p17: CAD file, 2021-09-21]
3d/ochin_cm4_plate_mount/ochin_plate+cover.FCStd
50.0 x 90.0 x 24.5 mm
ochin mount
cover+camera

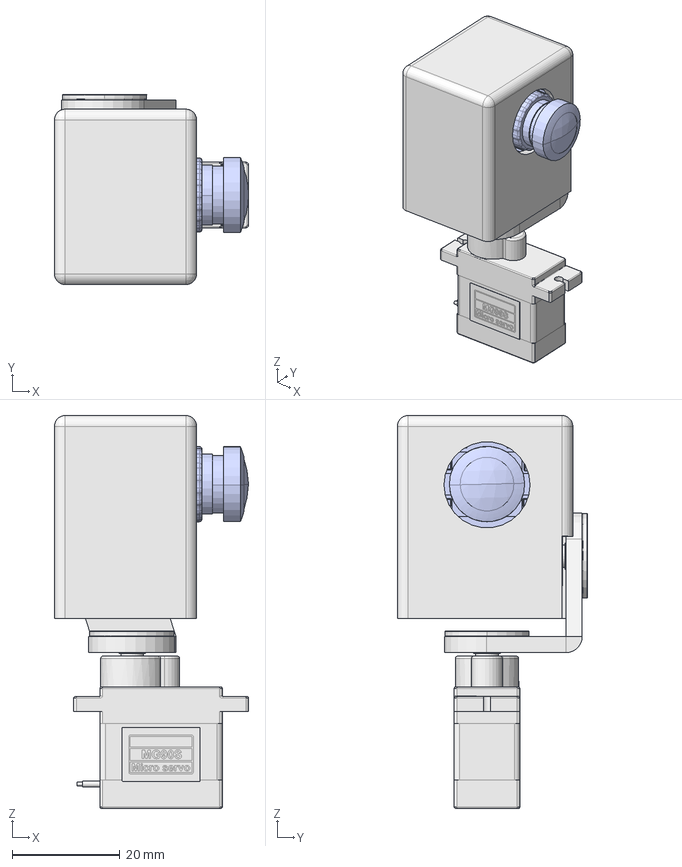
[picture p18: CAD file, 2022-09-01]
3d/camera microservo gimbal/camera_gimbal.FCStd
36.1 x 35.4 x 73.0 mm
Assembly servo inside
Assembly servo outside
rpiCameraM
rpiCameraM_lens
Assembly servo inside001
Assembly servo outside001
Micro sized Servo Mount - Round_Default
Micro sized Servo Mount - Round_Default001
PAN
Tilt

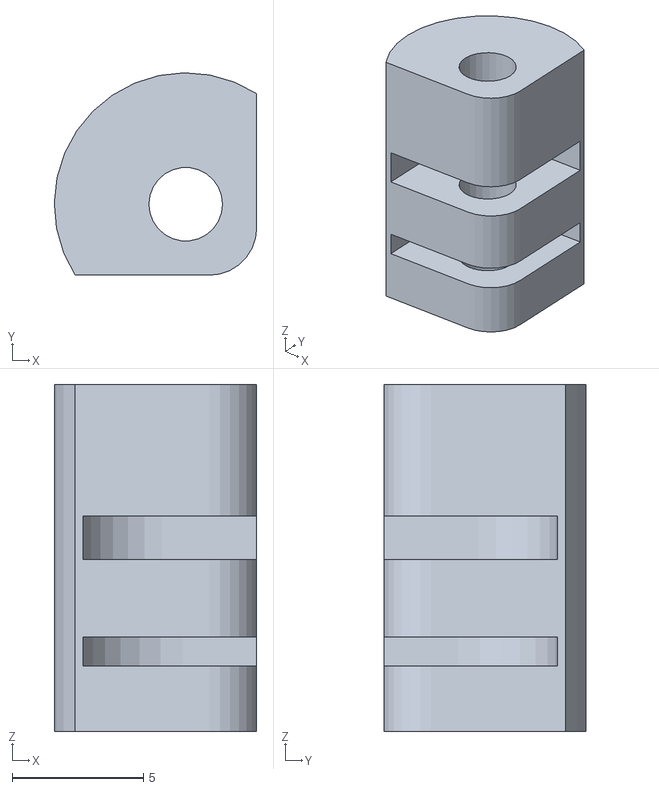
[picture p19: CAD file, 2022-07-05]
3d/Covers turrets and extractors/ochin_mount-turret.stl
7.70 x 7.70 x 13.2

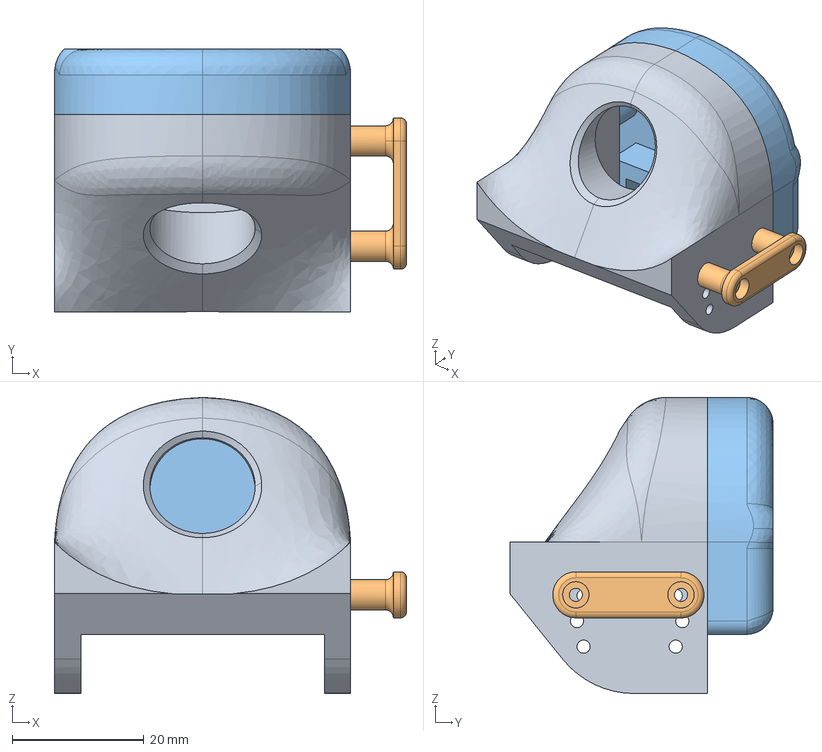
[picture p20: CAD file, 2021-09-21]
3d/EasyStar ii_IMX219_mount/EasyStar_camera_mount.FCStd
53.5 x 40.0 x 45.0 mm
supportoCam
staffa
coperchio

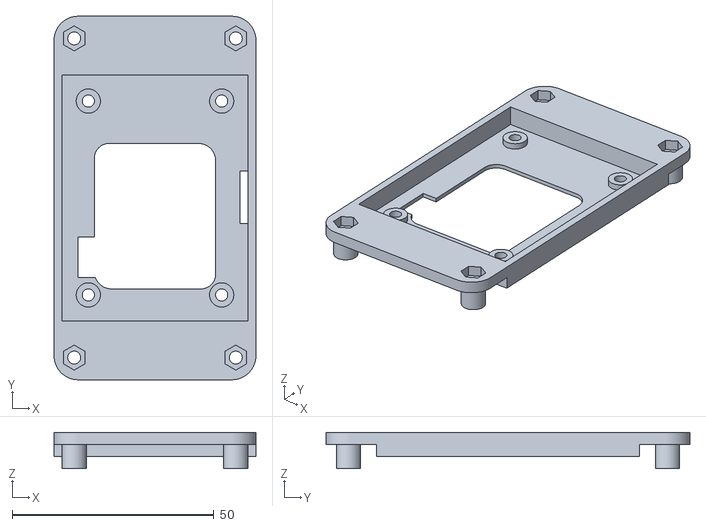
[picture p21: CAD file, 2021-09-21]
3d/ochin_cm4_plate_mount/ochin_plate.stl
50.0 x 90.0 x 9.00

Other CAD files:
3d/Covers turrets and extractors/ochin_mount-topCover.stl
3d/EasyStar ii_IMX219_mount/EasyStar_camera_mount_front.stl
3d/camera microservo gimbal/camera_gimbal_pan-PAN.stl
3d/Covers turrets and extractors/ochin_mount-botCover.stl
3d/camera microservo gimbal/camera_gimbal_tilt-Tilt.stl
3d/camera microservo gimbal/ochin_plate-Bot Plate.stl
3d/camera microservo gimbal/ochin_plate.FCStd

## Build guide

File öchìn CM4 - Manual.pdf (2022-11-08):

öchin CM4 carrier board manual v0.1 | 8 novembre 2022

## Introduction

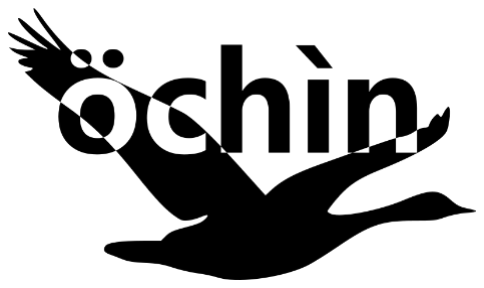
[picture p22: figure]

The öchìn CM4 it’s a tiny carrier board for the Raspberry Pi Compute Module 4. It is designed for applications where a powerful machine with low consumption and small dimensions is required. The small form factor makes it interesting for all those applications where the space available is not much and containing the weight is important, such as in robotics, home automation and IOT.

The board is compatible with all Raspberry Pi CM4 modules equipped with eMMC. Depending on your needs, you can select a CM4 module with an SDRAM starting from 1GB up to 8GB and the eMMC from 8GB up to 32GB, with or without the Wi-Fi / BT4 connection.

Key features of the Raspberry Pi CM4 available on öchìn are as follows:

- Broadcom BCM2711, Quad core Cortex-A72 (ARM v8) 64-bit SoC @ 1.5GHz
- Small Footprint 55mm × 40mm × 4.7mm module
- H.265 (HEVC) (up to 4Kp60 decode), H.264 (up to 1080p60 decode, 1080p30 encode)
- OpenGL ES 3.0 graphics
- Options for 1GB, 2GB, 4GB or 8GB LPDDR4-3200 SDRAM with ECC
- Options for 8GB, 16GB, or 32GB eMMC Flash
- Peak eMMC bandwidth 100MBytes/s
- 2.4 GHz, 5.0 GHz IEEE 802.11 b/g/n/ac wireless
- Bluetooth 5.0, BLE
- On board electronic switch to select between PCB trace or external antenna
- 1×USB 2.0 port (highspeed)
- MIPI CSI-2:
- 1×2-lane MIPI CSI camera port, 1×4-lane MIPI CSI camera port
- 1×USART, 3×UART, 1×I2C port, 1×SPI port, Analog Video Output

## Design

The board has the same dimensions as the RPi CM4 module, 55mm x 40mm with rounded corners. öchìn CM4 is composed of three parts, the carrier board itself and two covers, meant to protect the carrier board and the RPi CM4 module (to be purchased separately). The four cards thus form a stack of 18mm tall.
Several interfaces like USARTs, USBs are addressable bye the SM06B-GHS and SM04B-GHS connectors, available on the sides of the board. Two FCC/FPC connector are available to connect two MIPI CSI-2 cameras. The front camera is the “camera 1” which is a MIPI CSI-2 4lane camera. The side camera is the “camera 0” which is a MIPI CSI-2 2lane camera. The two FCC/FPC connectors have contacts on the bottom, the interface is the same used on the Raspberry Pi Zero.
On top of the board there is a 14x1.27mm connector, that could be used to connect a custom board on top, replacing the top PCB cover.
On the bottom of the öchìn carrier board there are the DF40HC(3.0)-100DS-0.4v mating connectors for the CM4 module. The bottom cover is meant to protect the boards and mount the whole stack. The bottom cover could be eventually replaced by a commercial heatsink for the CM4 module.

## Applications

The powerful Quad core Cortex-A72 CPU and GPU, the big RAM size and the CODECs and Graphic Accelerators available on the CM4 makes the system very interesting for a huge number of applications. Are suitable all the applications related to audio / video manipulation and streaming, neural networks, machine learning, computer vision, etc.

There are several communication interfaces available on board that enable the öchìn to connect to external hardware at lower abstraction layers, closer to the physical world.

An example of use could be a drone, where a flight controller board sense the physical references and control the actuators and motors to guarantee the stability of the flight. It could handle the stability of the vehicle, collect the data from the sensors and from the remote control and send the telemetry data back to the ground station. This is a very common structure nowadays for a UAS. The öchìn board could be used to add a wide range of functionality to the system.

The öchìn could handles up two MIPI cameras and others connected to the USB interfaces. Other sensors could also be added to the öchìn using the UART, SPI, I2C interfaces. All those data could be processed by several threads running on the CM4. The software infrastructure available within the CM4 enables to code with C/C++, python, MATLAB, and several other languages. There is also a wide number of frameworks that can be used to develop algorithms with Deep Learning, Neural Networks or Computer Vision technique, such as OpenCV, Caffe, PyTorch, TensorFlow etc. The öchìn board also provide the analog video output from the CM4. It means that it’s possible to create a video output from the whole set of data, including images and its elaboration, to transmit like a common analog video out. This is very convenient because it gives the chance to see the output of the processing in real time without taking care of creating a digital wireless bridge.

This is only an example, a similar structure could be though for rovers, submarines, airplanes, and robots in general. Of course, the öchìn board it’s very interesting for the IOT world also, where the size and weight is important. In this scenario, the AI is relevant and the tendency to miniaturize IOT devices and make them increasingly intelligent requires adequate hardware.

## Hardware interfaces

The öchìn CM4 board provides the following interfaces on the side’s connectors:

- 4x USB 2.0 480Mbps (4x SM04B-GHS-TB(LF)(SN) connectors)
- 1x USB Type-C (for flashing eMMC)
- 2x CSI camera (2x FH12-22S-0.5SH (55) connectors)
- I2C0 (SM04B-GHS-TB(LF)(SN) connector)
- SPI1 / 6 (SM06B-GHS-TB(LF)(SN) connector)
- UART0 / 1 + Video Out (SM06B-GHS-TB(LF)(SN) connector)
- UART3 / UART5 (SM06B-GHS-TB(LF)(SN) connector)
- USART4 (SM06B-GHS-TB(LF)(SN) connector)

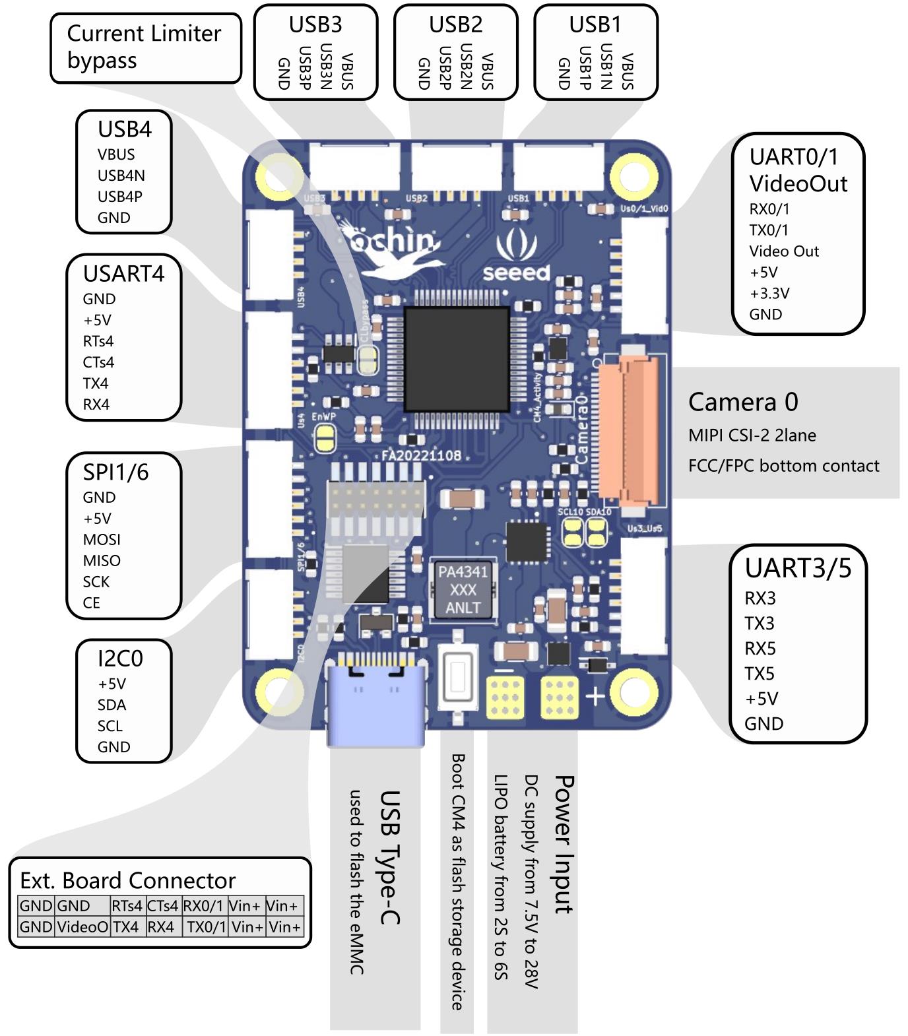
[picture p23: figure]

Top view

Bot view

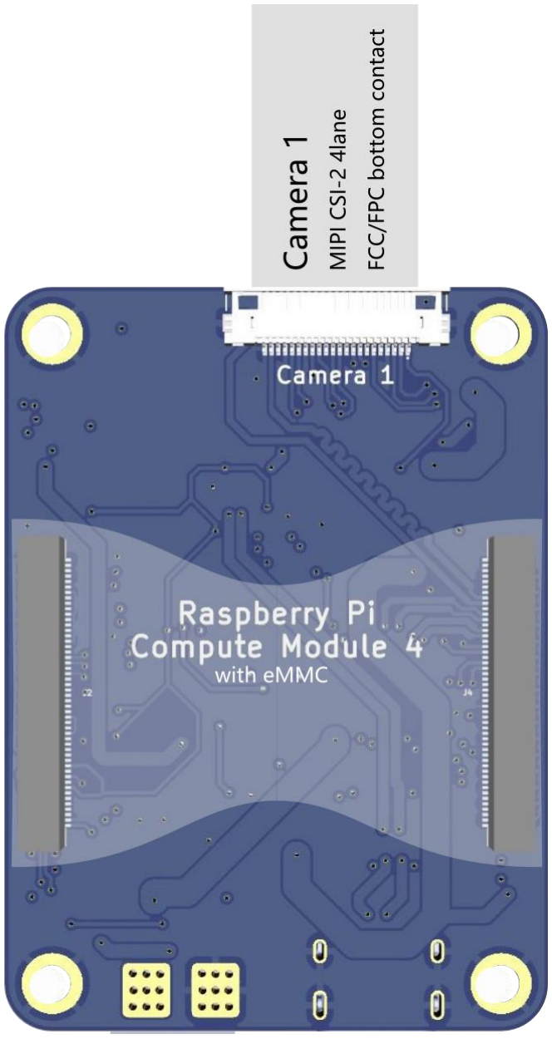
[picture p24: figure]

The I2C0 interface is available on the connector, but it is shared with the Camera0.

To disconnect the I2C0 from the Camera0, it is necessary to cut the two solder-jumper

on the board:

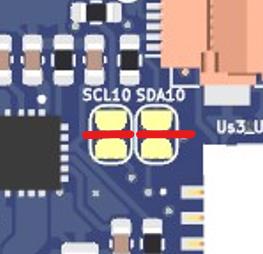
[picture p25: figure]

To write protect the eMMC it’s necessary to short the jumper EnWp:

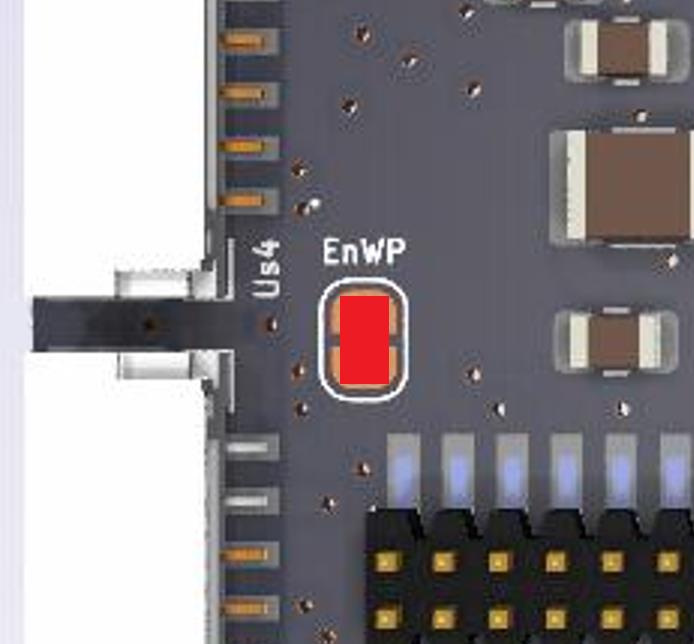
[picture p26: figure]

## The Current Limiter

The IC4 - AP22615AWU-7 is a single-channel current-limited high-side
power switch with output OVP optimized for USB and other hot-swap
applications. On the ochin_CM4 board, the current threshold of the AP22615AWU-7 is set to 3A. If the IC4 it’s triggered, it will cut the VBUS on the USBs to keep the CM4 supplied while an overcurrent condition happens. There are four possible condition that triggers the current limiter:
(from the AP22615 datasheet Document number: DS41022 Rev. 5 – 2):

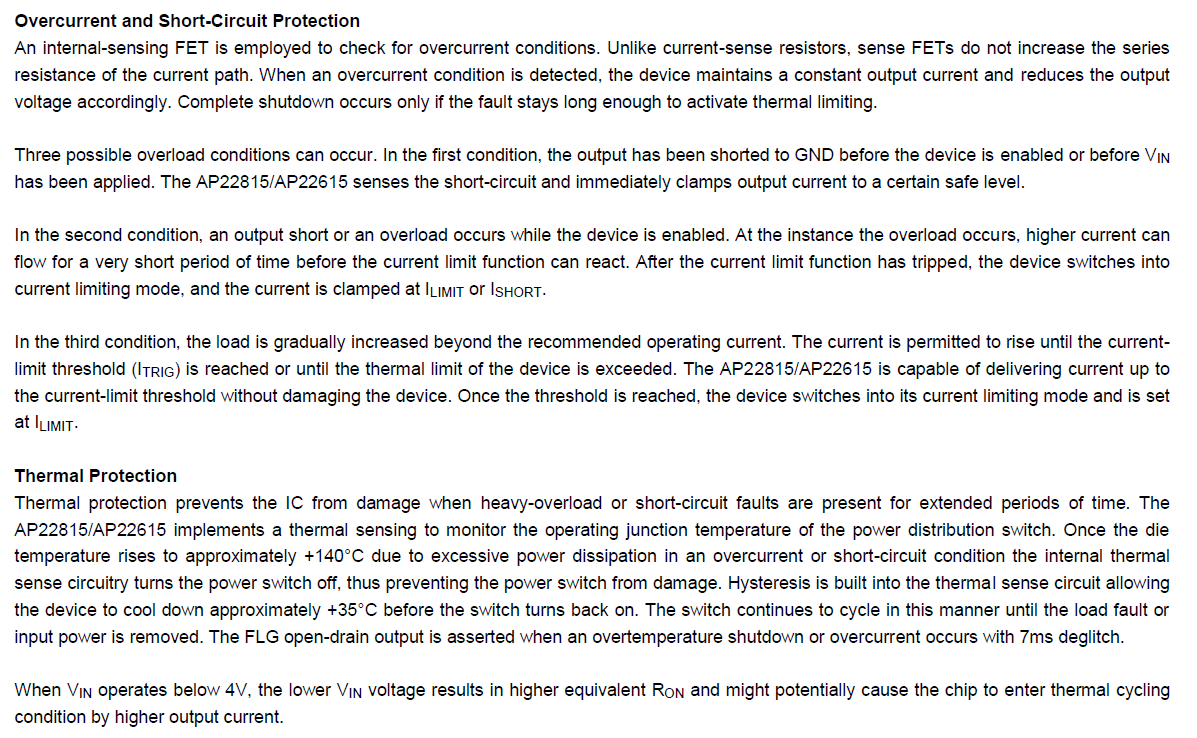
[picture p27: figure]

In the case you need more current on the USBs, it’s necessary to remove the IC4 -

AP22615AWU-7 and short the JP4 (CLbypass). Before short the JP4 it’s important that

IC4 has been removed. If the current limiter is not present, the USBs supply is directly

connected to the output of the +5V switching regulator, the same that supply the CM4.

The power supply can provide up to 8A, leaving 2A for the CM4 (the manual says 1.4A

but better be conservative), 6A remain available for the USBs and the external

peripherals. That said, before remove the limiter it’s important to know how much

current the external devices will drawn, to leave the juice for the CM4 or it will reboot.

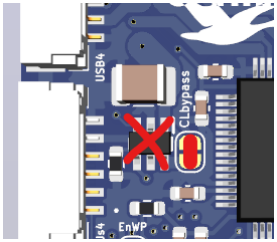
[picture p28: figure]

## Software Configuration

The öchìn board is only compatible with CM4 module with eMMC installed, because we

decided to not mount the SD card slot to save space. Having the eMMC instead of SD

also gives several advantages:

1. Faster than SD with speed up to 100Mbytes/s
2. More robust to physical corruption
3. Longer lifetime
4. More rugged

Having to write the ISO image directly to the eMMC is a bit more complicated than flash

an SD card, but not so much thanks to the great work done by Raspberry Pi.

The procedure to flash the CM4 module is well explained in the Raspberry Pi

Documentation:

https://www.raspberrypi.org/documentation/hardware/computemodule/cm-emmc-flashing.md

The procedure it’s straightforward, what you need to do in synthesis is the following:

1. Power up the board with boot configuration as “mass storage device”.
- To do so you need to power off the board (no Vin connected)
- Press the “nRPiboot” button and, keeping it pressed power up the board

using the “Vin” Connector.

- Connect the board to your PC using the USB Type-C port

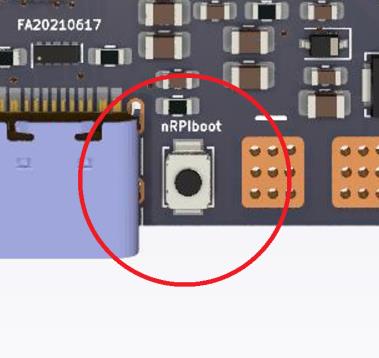
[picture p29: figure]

2. Run the “RPiboot” software, downloaded from the Raspberry Pi website. (https://github.com/raspberrypi/usbboot/raw/master/win32/rpiboot_setup.exe) After the

software starts, the PC will see the partition of the eMMC like if it would an SD

into the SDcard reader.

3. Flash the eMMC as you normally do with the SD. You could use Win32DiskImager

on Windows or “dd” command on Linux.

Once you have the system running for the first time, the USB interface will not work

because on CM4 it is disabled by default. To use the USBs, you need to enable them in

the “config.txt” file, adding the following line at the end of the file:

dtoverlay=dwc2,dr_mode=host

The “config.txt” file could be found within the “boot” partition. To be noted is that the

“boot” partition is also accessible when you connect the CM4 to the PC booted in MSD

mode, since it is formatted as FAT32.

NB

The Type-C VBUS is not connected to the power supply of the ochin board. This is to

not supply everything you may have attached to the HUB (Wi-Fi dongle, cameras etc..),

the power provided by the PC may not be sufficient. It means that if you only plug the

USB Type-C nothing is going to happens... To power on the board the supply on the

Vin connector is needed.

The Type-C VBUS it is used to switch the CM4 usb from the HUB to the Type-C port,

this is to be able to flash the eMMC. For this reason, during the normal operations, the

Type-C connector shouldn't be connected to anything.

## Schematics

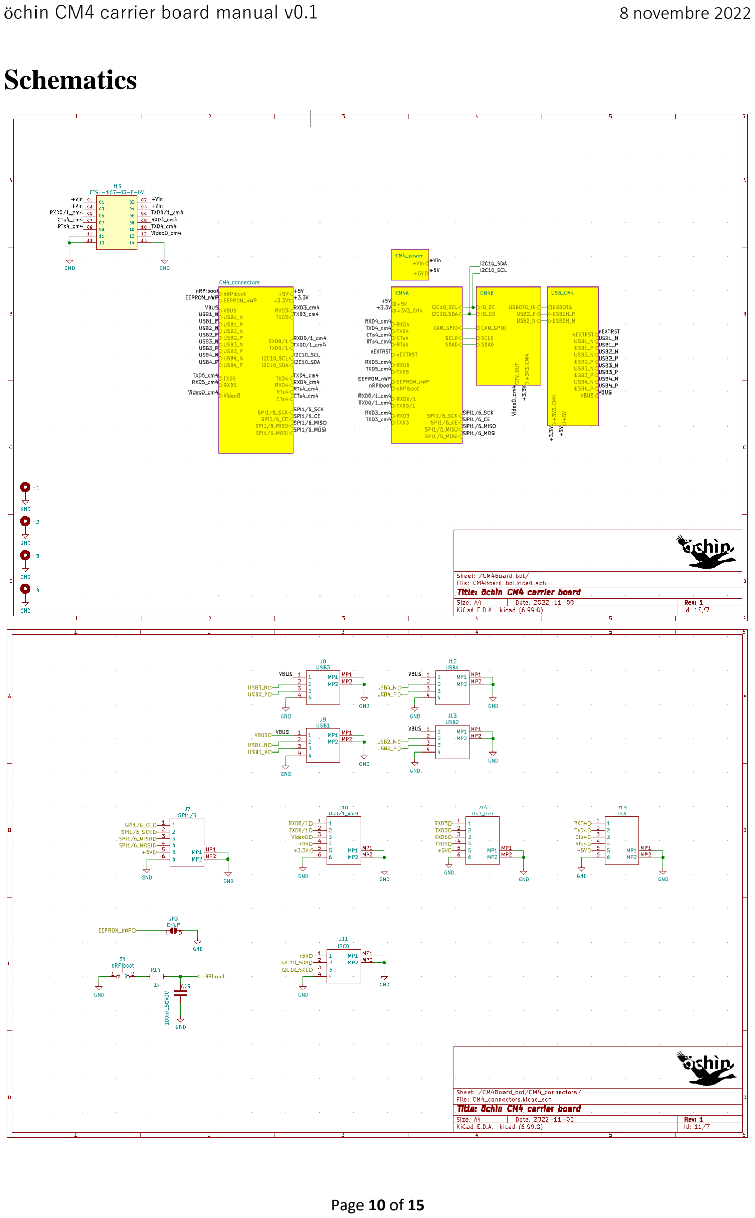
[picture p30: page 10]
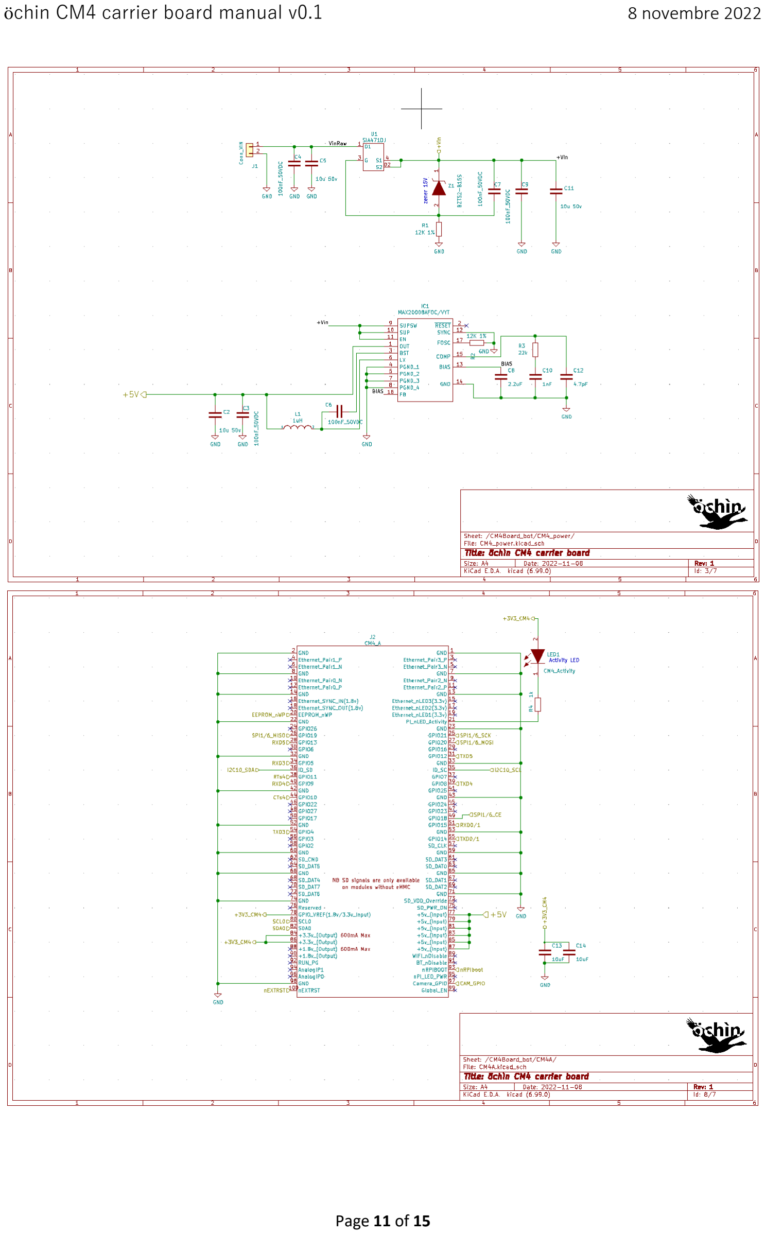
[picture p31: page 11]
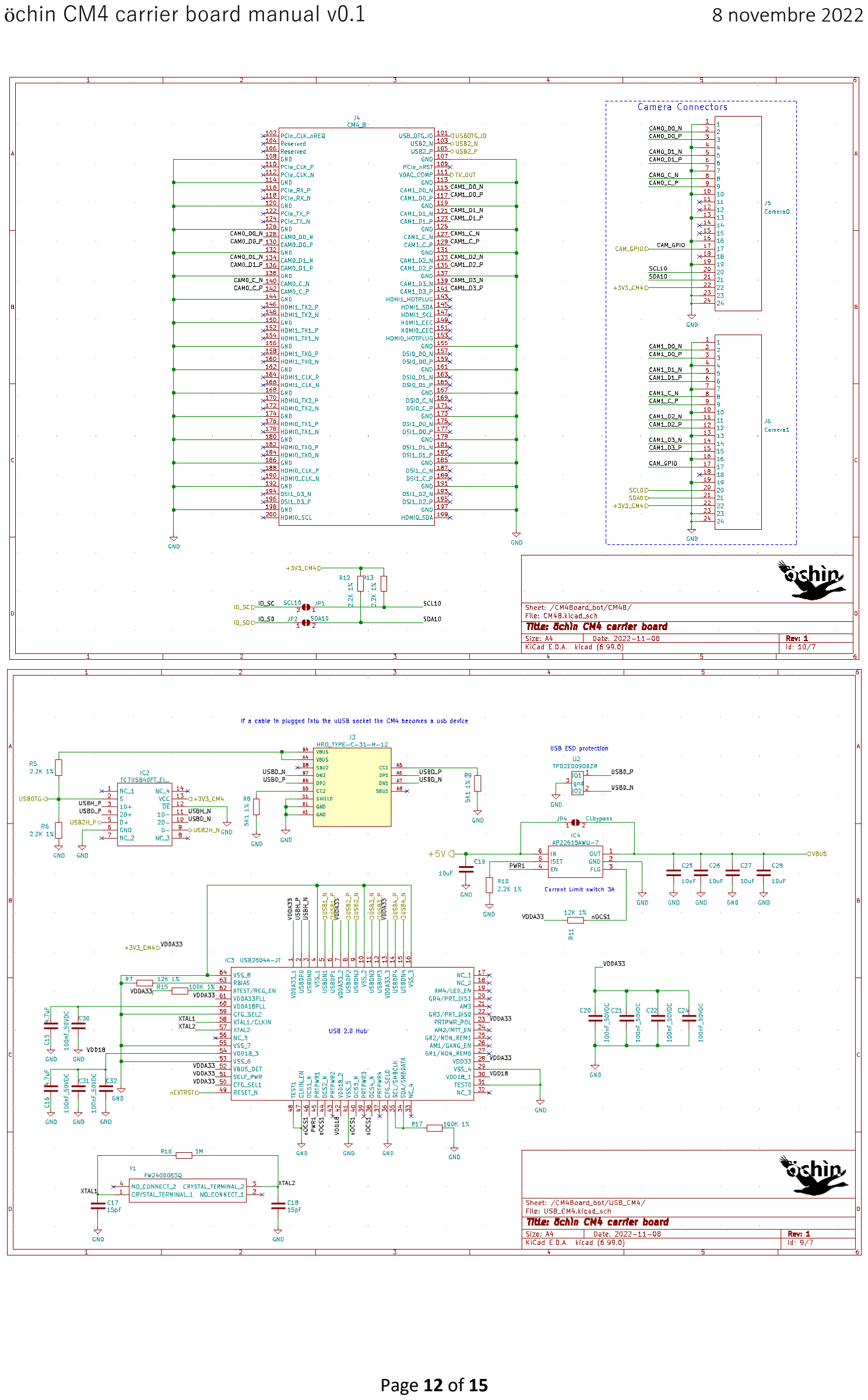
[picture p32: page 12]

## PCB layers

TOP

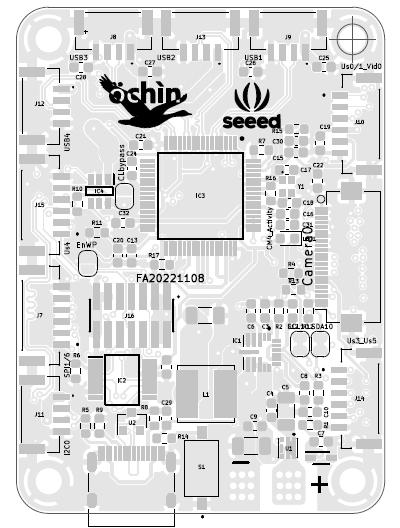
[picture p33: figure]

Inner Layer 1

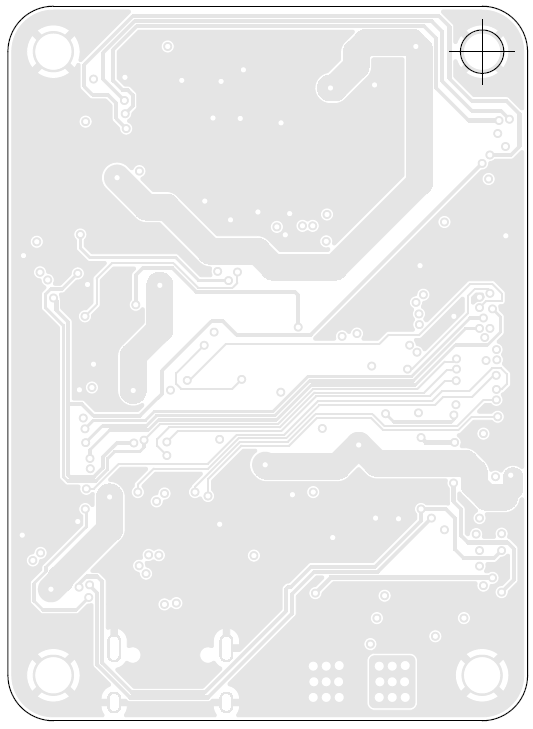
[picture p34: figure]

Inner Layer 2

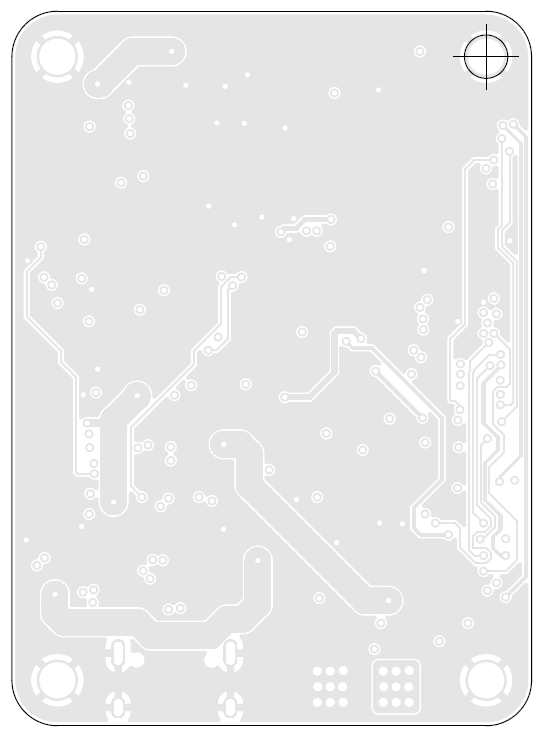
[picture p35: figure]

BOT

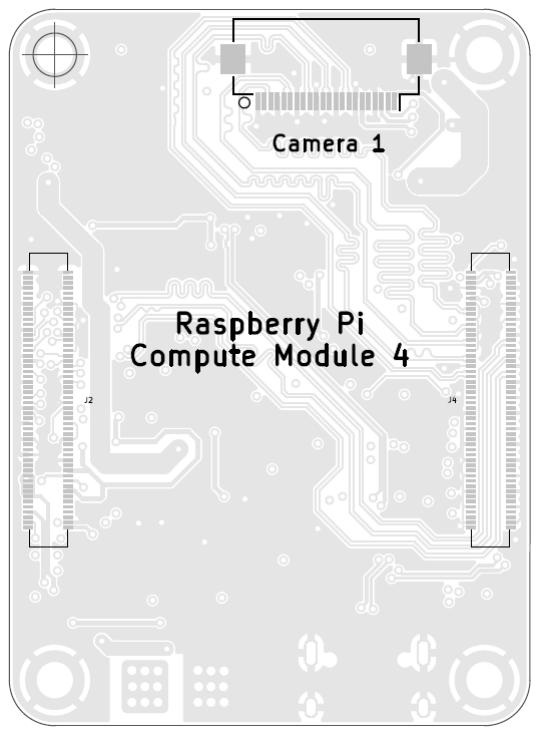
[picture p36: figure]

## Mechanical stack view

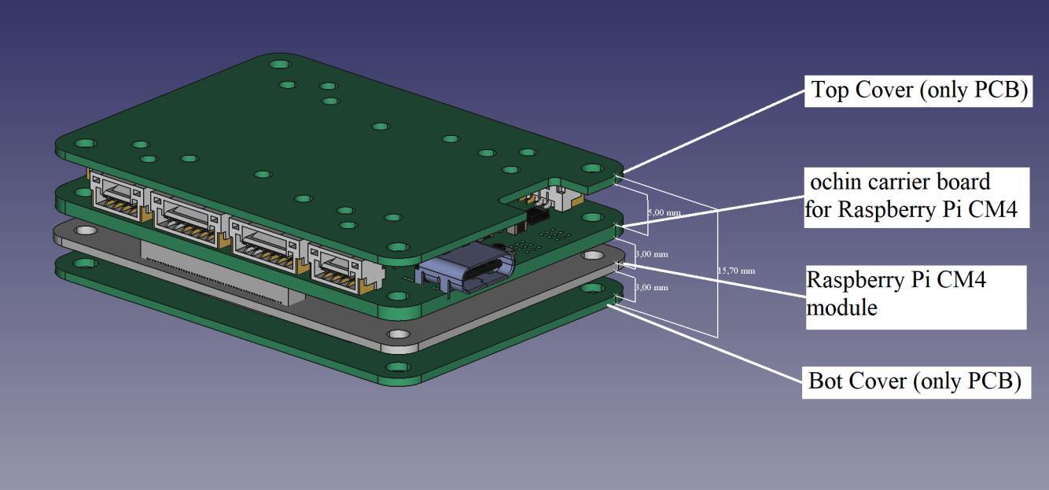
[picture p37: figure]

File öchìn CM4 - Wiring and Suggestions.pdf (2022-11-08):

öchin CM4 Wiring and Suggestions v0.1 | 8 novembre 2022

## Introduction


this document aims to show one of the possible ways to make connections on the ochin_CM4 board, considered by the writer to be a good way. In addition, some aspects are brought to the attention of the reader that can help avoid the onset of problems of various kinds.

## Power Supply

The card accepts input voltages up to 28V, its internal regulator supplies 5V with currents up to 8Amps, therefore it is advisable to use cables with an adequate section. Choosing a cable with an adequate section avoids too high voltage drops. It is advisable to choose a cable with a section no longer less than AWG14.

The pads on which the power cables are soldered are copper squares perforated by a matrix of 9 metallized holes. The purpose of these vias is to increase the conductive surface by putting the 4 layers of the pcb in contact and to provide more mechanical strength. In fact, once the wires have been soldered to the pcb, the tin that crosses the vias and reaches the bottom layer becomes a mechanical block through the pcb. This prevents the Top layer pads from tearing off the pcb following an accident. It is therefore advisable to verify that the pond has passed through the vias to the bottom layer.

## GHS cables

Except for the two cameras, the USB Type-C and the power pads, all other interfaces are accessible via 4 or 6 pin GHS connectors. Whether the cables with the connectors are purchased separately or supplied by Seeedstudio together with the ochin_CM4 board, it is important to NEVER TRUST THE COLOR CODE , because the color sequence of the cables can change from one manufacturer to another and is often random. So before connecting anything to the board it is important to check that the connections are correct regardless of the color of the cables.

Eventually it is possible and advisable to move the cables in the connector to have the colors consistent with their function.

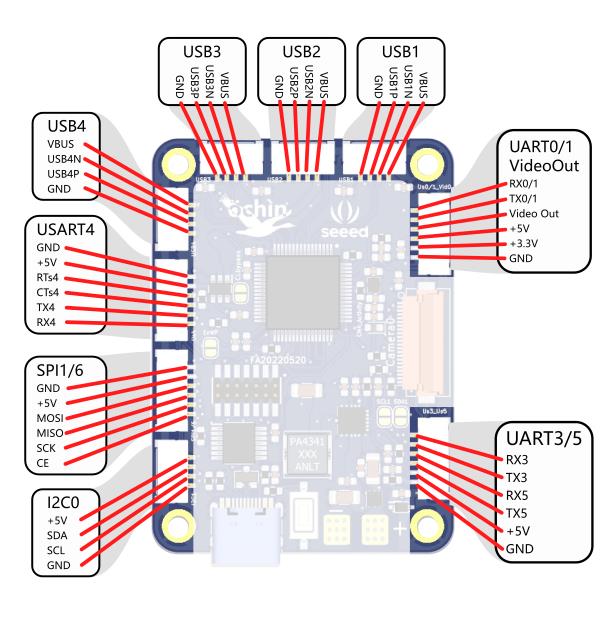
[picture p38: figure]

## USBs

The connections related to the USB ports are a bit critical, the reason for their criticality is the high frequency at which the USBs work. The maximum speed at which USB2 works is 480Mbps and at this frequency is very important to ensure impedance coupling to avoid reflections and other deleterious phenomena. Understanding these phenomena requires in-depth studies and this document does not purport to explain any of this. This paragraph has the sole purpose of warning the reader that the connection of a USB device is not made by any 4 wires, as it can be for a serial or I2C device. The ochin_CM4 board uses SM04B-GHS connectors for USB which are not the standard connectors with the aim of saving space, therefore it is not possible to use normal USB cables to connect devices to the board. However, it is advisable to connect a shielded USB cable to the GHS connector, cutting the wires as short as possible, because in the USB cable the cross-section of the wires, the material and thickness of the insulation and the way in which D + and D- are twisted make ensure that the cable has the right impedance. To do this, you can cut an USB extension cable and replace one of the connectors with the GHS.

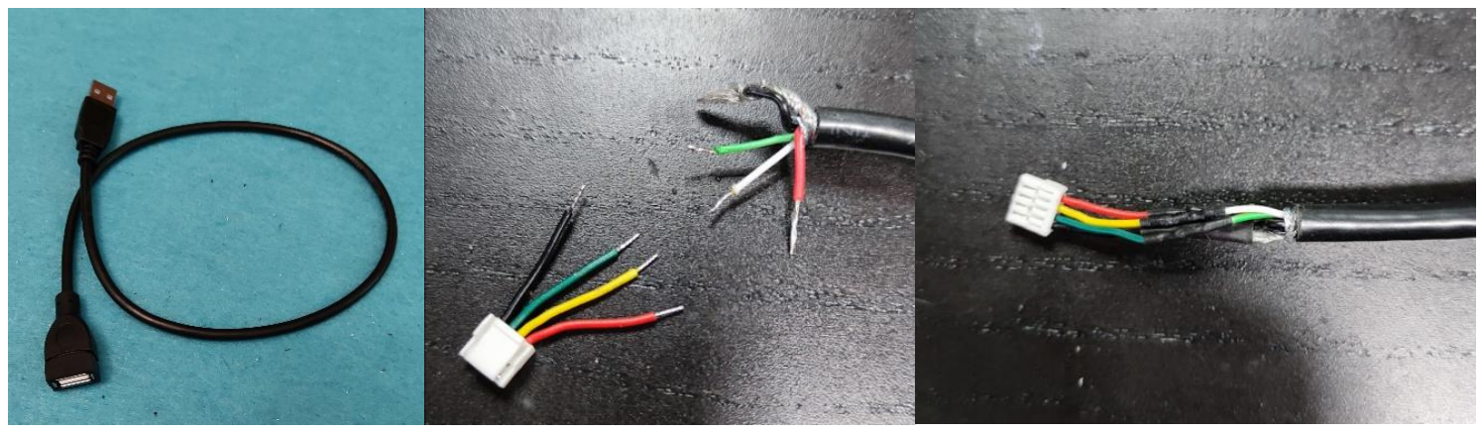
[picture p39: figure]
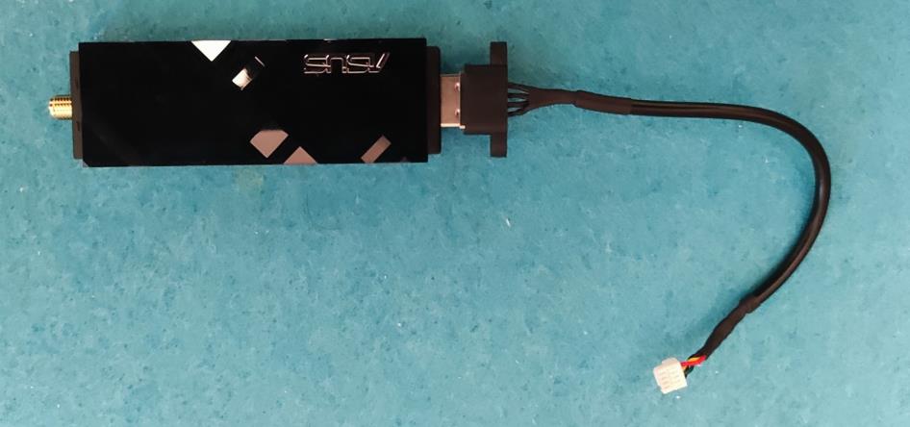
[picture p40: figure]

There are several models of connectors compatible with flat cable manufacturers for Raspberry Pi Zero cameras (MIPI CSI 22 contacts 0.5mm pitch). After several tests of all compatible models, despite the not very small size, it was decided to use Hirose Electric FH12-22S-0.5SH (55). The main reasons are greater mechanical strength and easier positioning of the flat cable. However, it is important to be very careful to position the terminal part of the flat cable correctly and prevent the flat from being removed without having deactivated the mechanical block of the connector. If the flat is pulled out when blocked, it may happen that the pins of the connector scratch the copper surface of the contacts. In this case, seemingly random phenomena often occur in which the camera suddenly stops working or does not work at all. In these cases, it is advisable to check the status of the contacts with a magnifying glass.

It is also important to avoid subjecting the flat cable to too tight bends because they can cause the breakage of the support and the interruption of the connections printed on it.

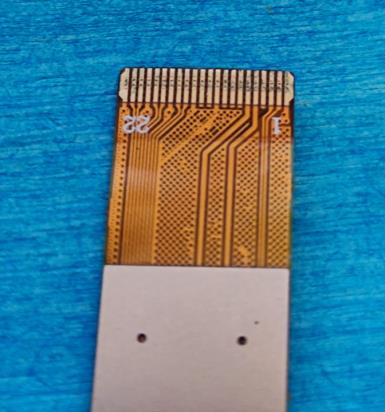
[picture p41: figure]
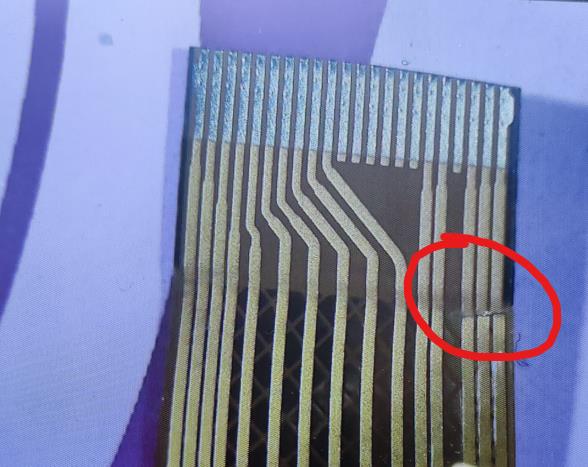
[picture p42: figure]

It is suggested to shield the flat cable. This has the dual function of shielding the camera signals and providing more strength to the flat cable. To obtain a good shielding it is advisable to use the 30mm copper adhesive tape (sufficient width to cover the flat on both sides).

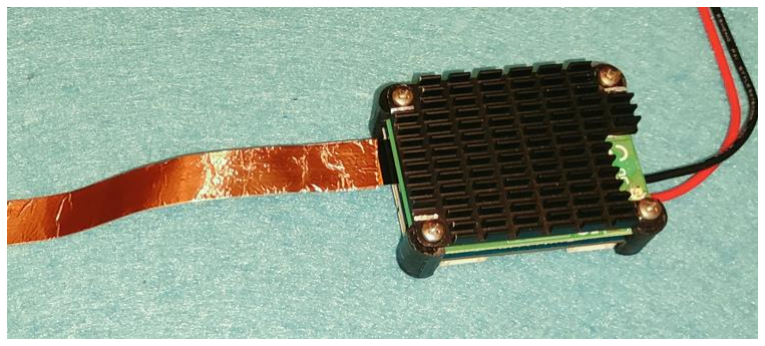
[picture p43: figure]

## Raspberry CM4 module mezzanine connectors

To mount the raspberry pi CM4 module, there are two 100 pins connectors on the back of the ochin_CM4 board. The two connectors are not vertically centered on the board, so it is quite easy to understand how the module is inserted. If the CM4 module is correctly inserted, the 4 mounting holes coincide with those of the ochin_CM4 board, otherwise the two remain misaligned.

The connectors are quite delicate and very dense, so you need to be careful. Before positioning the CM4 module, it is advisable to check that there are no specks of dust or other things that could prevent contact of the pins, if necessary clean with a soft brush and air. Place the module gently on the connectors until you feel they are seated in each other (there is a first zero force step where they snap into). When you are sure that the two boards are perfectly aligned and the connectors engaged, press the two long edges of the CM4 module until the connectors are fully inserted. It is advisable to limit the disassembly of the CM4 module as much as possible to avoid damaging the connector contacts.

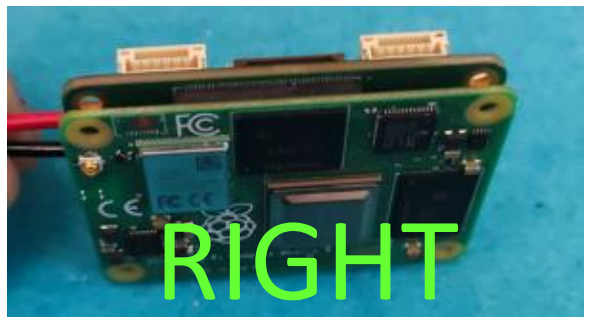
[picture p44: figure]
RIGHT
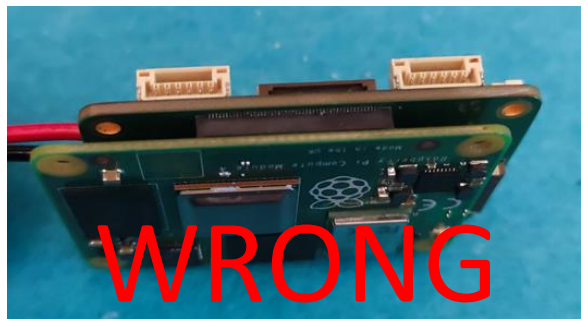
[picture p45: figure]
WRONG

Removing the CM4 module from the ochin_CM4 board is even more critical than mounting. If the module is removed in an inappropriate manner, the two boards will remain misaligned during the release of the mezzanines, and it is very likely that the male connector (CM4 module side) will be damaged.

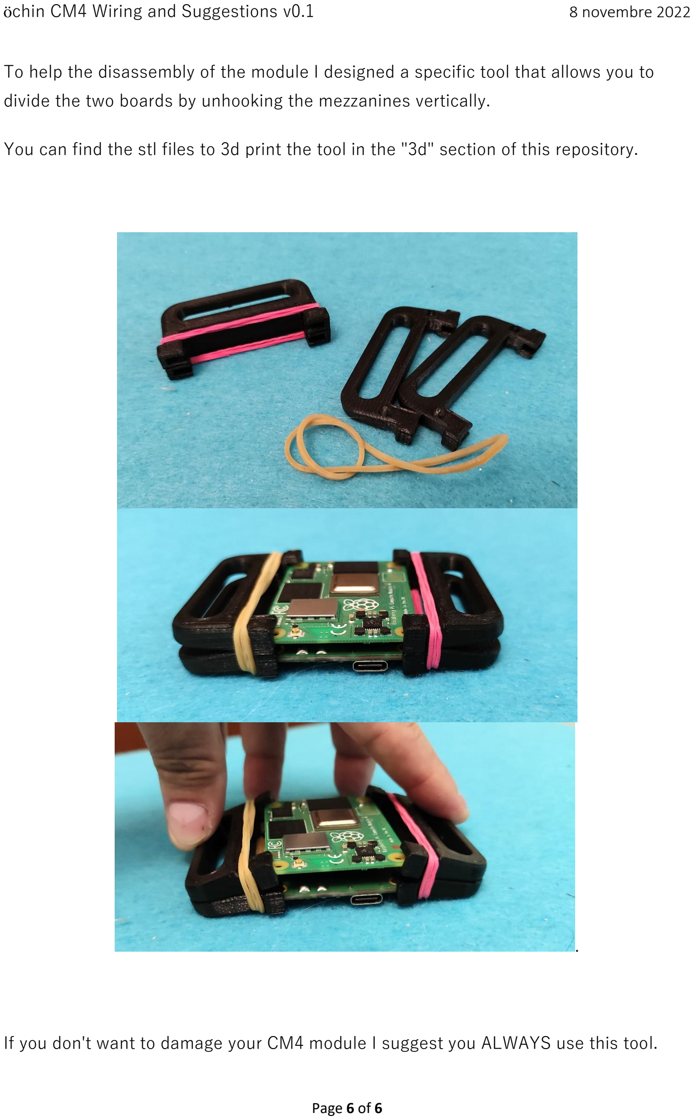
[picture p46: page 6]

To help the disassembly of the module I designed a specific tool that allows you to divide the two boards by unhooking the mezzanines vertically.

You can find the stl files to 3d print the tool in the "3d" section of this repository.

If you don't want to damage your CM4 module I suggest you ALWAYS use this tool.

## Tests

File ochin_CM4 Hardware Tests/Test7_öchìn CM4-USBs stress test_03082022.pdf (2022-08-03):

Ochin CM4 carrier hardware tests v0.1 | 3 agosto 2022


## ochin_CM4 Hardware test number 7

## USBs stress test

Devices used for tests

1. ochin CM4 carrier board
2. Raspberry Pi CM4 module with eMMC
3. Power Supply 0-30Vdc
4. Raspberry Pi Zero configured as Gadget Zero Device
5. 1x usb type-c cable
6. 1x GHS 4pin to usb Type A cable

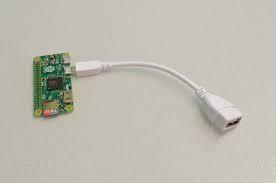
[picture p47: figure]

Test description

The Raspberry Pi CM4 module provides only one USB port, which is used both to flash

the eMMC of the cm4 and for the normal use of the board to connect devices.

The ochin board has a 4ports USB-HUB, connected to the CM4 module, in order to

increase to 4 the number of the USB ports.

This test is intended to verify the operation of the USB interfaces for long sessions of

reads and writes in different modes. The goal is to verify the robustness of the system, testing both the integrated components involved, the connections and couplings

between them.

The program used to test the USBs is the "testusb.c" file, already present and compiled

in linux OS and designed for the purpose of testing USB device drivers.

To carry out the test, another hardware device must be connected to the affected USB port. This device must contain software capable of answering calls on the USB port for the test to be successful. In our case we use a Raspberry Pi 4 or a Raspberry Pi Zero in a mode called "Gadget Device Zero".

From http://www.linux-usb.org/gadget/

Gadget Zero ... is essential for controller driver testing. (http://www.linux-usb.org/usbtest/index.html#gadgets) It provides two configurations: one for bulk traffic source/sink, and another for bulk traffic loopback. On the device side it helps verify that the driver stack pass USB-IF and other tests (needed for at least USB branding). On the host side it helps test the USB stack, such as the Linux-USB HCDs and usbcore. If built as a module, start it by modprobe g_zero; no other initialization is needed.

It is important to use an RPi4 or an RPi Zero because the USB must also work in device mode (it is not the case for the other Raspberry models). For the sake of the test, the /dev/zero source will be used since it’s a device file which generates a continuous stream of zeros. It could be also used as destination path, in which case it will accept ad discards all data written to it.

Preliminary Configuration

Prepare the Raspberry Compute Module 4 + ochin board:

1: flash the Raspberry Pi OS Lite Debian version 10(buster) to the sd (link: https://downloads.raspberrypi.org/raspios_oldstable_lite_armhf/images/raspios_oldstable_lite_armhf-2022-04-07/2022-04-04-raspios-buster-armhf-lite.img.xz )

I suggest to use the Raspberry Pi imager software, in order to also configure the WiFi network and enable the ssh.

2: enable the USB interface (disabled by default on CM4). Edit the file “/boot/config.txt” and add

dtoverlay=dwc2,dr_mode=host

at the end of the file

3: copy the content of the testusb.zip file in the home folder

4: install "screen" with "sudo apt-get install screen" , this is needed to keep the test running even if you disconnect from terminal

Prepare the Raspberry Pi 4 to function as a device:

1: flash the Raspberry Pi OS Lite Debian version 10(buster) to the sd (link: https://downloads.raspberrypi.org/raspios_oldstable_lite_armhf/images/raspios_oldstable_lite_armhf-2022-04-07/2022-04-04-raspios-buster-armhf-lite.img.xz )

I suggest to use the Raspberry Pi imager software, in order to also configure the WiFi network and enable the ssh.

2: edit the file “/boot/cmdline.txt” and add

modules-load=dwc2,g_zero

at the end of the first line

3: edit the file “/boot/config.txt” and add

dtoverlay=dwc2

at the end of the file

At this point the Raspberry Pi 4 is ready to work as a device. For this to happen it is necessary to connect the USB Type-C connector of the RPi4 to one of the 4 USB ports of the ochin board.

At boot the Raspberry Pi 4 will realize that it is connected to a USB port (and not to a power supply as usual) and will enter "Gadget Device Zero" mode.

To do so, you will need a USB Type-C data cable and a GHS 4Pin <-> USB Type-A (female) adapter cable.

To build the GHS USB adapter cable please look at the "öchìn CM4 - Wiring and Suggestions.pdf" doc, page 3/5.

Test execution

NOW YOU'RE READY TO START THE TEST

1: connect the RPi4 to the first USB port of the ochin board (using the adapter cables)

2: power on the ochin board

3: connect to the CM4 via ssh

4: sending the "lsusb" command you should see the list of the usb interfaces and the

"Gadget Device Zero" connected

5: use screen and the test2file.sh script to start the test logging the result to a file and

keep it running after the terminal disconnects (this is for long runs)

screen sudo ./test2file.sh USB3_test1_ochin_CM4.txt

not the test is running in the background...

to see the active screen process:

screen -list

There is a screen on:

2410.pts-3.pi | (19/02/22 16:10:26) | (Attached)

1 Socket in /run/screen/S-pi.

to stop the screen process

screen -X -S "2410.pts-3.pi" quit

For the repetitive execution of the "testusb.c" software, the "test.sh" script was used,

which runs the test in the following modes indefinitely.

usbtest 2-2.4:3.0: TEST 0: | NOP
usbtest 2-2.4:3.0: TEST 1: | write 512 bytes 1000 times
usbtest 2-2.4:3.0: TEST 2: | read 512 bytes 1000 times
usbtest 2-2.4:3.0: TEST 3: | write/512 0..512 bytes 1000 times
usbtest 2-2.4:3.0: TEST 4: | read/512 0..512 bytes 1000 times
usbtest 2-2.4:3.0: TEST 5: | write 1000 sglists 32 entries of 512 bytes
usbtest 2-2.4:3.0: TEST 6: | read 1000 sglists 32 entries of 512 bytes

usbtest 2-2.4:3.0: TEST 7: | write/512 1000 sglists 32 entries 0..512 bytes
usbtest 2-2.4:3.0: TEST 8: | read/512 1000 sglists 32 entries 0..512 bytes
usbtest 2-2.4:3.0: TEST 9: | ch9 (subset) control tests, 1000 times
usbtest 2-2.4:3.0: TEST 10: | queue 32 control calls, 1000 times
usbtest 2-2.4:3.0: TEST 14: | 1000 ep0out, 0..255 vary 1

For this test, we have chosen to stop the execution after 4 hours for each USB port.

For more information about the USB Testing on Linux, please follow this link (http://www.linux-usb.org/usbtest/) .

Test result

The test worked as expected and took 16 hours in total. The log file related to the tests

done on each port could be found in the “ochin_CM4_USBstresstest_MMYYYY.zip”

file.

Test Passed

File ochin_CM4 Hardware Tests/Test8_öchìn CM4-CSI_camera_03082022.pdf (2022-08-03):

Ochin CM4 carrier hardware tests v0.1 | 3 agosto 2022


## ochin_CM4 Hardware test number 8

## CSI cameras test

Devices used for tests

1. ochin CM4 carrier board
2. Raspberry Pi CM4 module with eMMC
3. Power Supply 0-30Vdc
4. CSI camera

Test description

the purpose of this test is to verify the proper functioning of the two CSI interfaces, available on the ochin board. To test the CSI cameras we will use a software called mjpg-streamer, able to display the stream of the cameras on a web page.

Preliminary configuration

The ochin_CM4 board allow to connect 2 CSI camera at the same time.

Since every camera needs a I2C interface, one I2C interface is shared between the

Camera0 (the one on the side of the board)

and one of the GHS connectors (for external i2c devices).

To be able to use the Camera0 is needed to short the two smd jumper (SCL1 and

SDA1) close to the Camera0 connector.

Please look at the ochin_cm4 manual at page 6.

To enable the CSI Cameras interfaces is also needed to load the proper device tree at

boot. The dt-blob.bi, present in the “files” folder of this github repository, enables both

cameras. To load it at boot it must be copied inside of the "/boot" folder of the CM4.

After placed the device tree within the "/boot" folder shut down the CM4 and mount the cameras to the board.

Once rebooted, if the cameras have been found, you should be able to find them as "/dev/video0" and "/dev/video1".

issuing:

ls /dev/video*

you should receive:

/dev/video0 /dev/video10 /dev/video12 /dev/video14 /dev/video16

/dev/video1 /dev/video11 /dev/video13 /dev/video15 /dev/video18

and issuing:

vcgencmd get_camera

you should receive (with 2 camera connected):

supported=2 detected=2

Installation of mjpg-streamer:

sudo apt-get update

sudo apt-get upgrade

sudo apt-get install cmake libjpeg8-dev imagemagick git

we clone the jacksonlian branch because is compatible with raspicam git clone https://github.com/jacksonliam/mjpg-streamer

cd mjpg-streamer/mjpg-streamer-experimental

open the file "utils.c" and comment out the following lines:

//#include <linux/stat.h>

//#include <sys/stat.h>

compile teh software issuing:

make

after compiled you're ready to stream the camera to a webpage.

find the cm4 ip address (for later use):

ifconfig

Test execution

Start streaming issuing:

./mjpg_streamer -i "./input_uvc.so -d /dev/video0 -f 30 -r 1280x720" -o

"./output_http.so -w ./www"

modify /dev/video0 to /dev/video1 to change the camera

To watch the camera stream, open a browser on a pc (in the same subnet of the CM4):

http://CM4_ipaddress:8080

and select "stream" on the left menu

Test result

Test passed for both cameras

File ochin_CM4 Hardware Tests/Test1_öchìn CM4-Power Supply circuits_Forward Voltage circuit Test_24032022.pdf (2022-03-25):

Ochin CM4 carrier hardware tests v0.1 | 23 marzo 2022


## ochin_CM4 Hardware test number 1

## Power Supply circuits:

## Forward Voltage circuit

Devices used for tests

1. ochin CM4 carrier board
2. Raspberry Pi CM4 module with eMMC
3. Multimeter
4. Power Supply 0-30Vdc

Test description

This test is intended to verify the operation of the power supply circuit for the CM4

module. First you need to check that the reverse voltage protection mosfet lets the

input voltage pass. Secondly, it is necessary to measure that 5Vdc is present on the

output of the switching regulator for the power supply of the Raspberry Pi CM4

module.

Test execution

1. In this phase the CM4 module SHOULD NOT BE MOUNTED on the ochin carrier

board since it is not needed for the test.

2. Apply a voltage between 7,5Vdc and 25Vdc on the power pads. The positive pole

is the one on the right and the negative pole is on the left (top view).

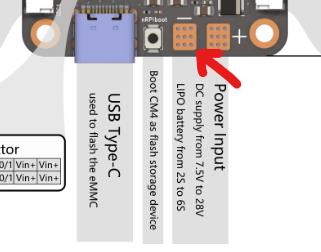
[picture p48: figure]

3. Verify the voltage on the source pin of the SIA471DJ mosfet, placing the

multimeter across the C11 capacitor. The voltage pass through the mosfet and

we should find on C11 the same voltage of Vin.

4. If the voltage on C11 is fine, it is possible to verify the +5V on the output of the

switching regulator. To check the +5Vdc we can measure the voltage across C2.

The measured voltage should be +5Vdc.

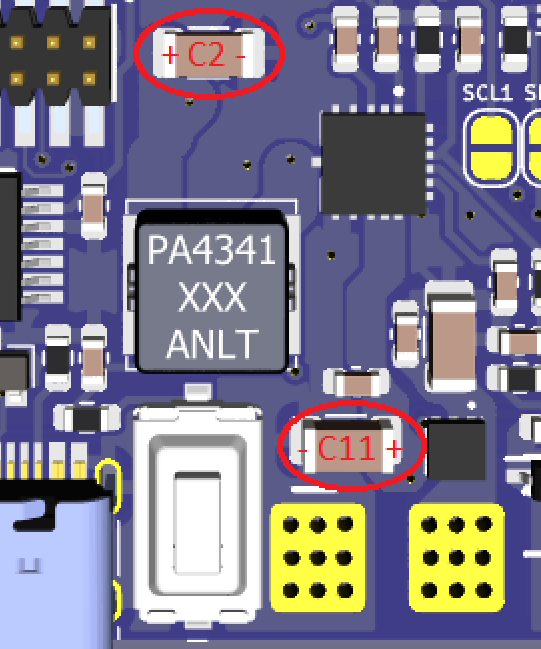
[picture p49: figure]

Test results

The test was performed numerous times on different boards and never presented any

problems.

Test Passed

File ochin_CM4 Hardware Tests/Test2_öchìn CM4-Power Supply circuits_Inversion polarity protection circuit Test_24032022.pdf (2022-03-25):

Ochin CM4 carrier hardware tests v0.1 | 23 marzo 2022


## ochin_CM4 Hardware test number 2

## Power Supply circuits:

## Inversion polarity protection circuit

Devices used for tests

1. ochin CM4 carrier board
2. Raspberry Pi CM4 module with eMMC
3. Multimeter
4. Power Supply 0-30Vdc

Test description

The ochin board is equipped with a reverse polarity protection circuit. The power supply

is blocked in case of inversion, thanks to the U1-SIA471DJ mosfet. In the case that the

Vin is mistakenly reversed, the gate of the mosfet-p opens the junction, preventing

current to pass damaging the board.

Test execution

To verify the functioning of the U1-SIA471DJ mosfet, it is necessary to arbitrarily invert

the polarity of Vin and therefore check that the voltage across C11 is equal to zero.

1. To prevent the CM4 module from being damaged in the event of a protection

malfunction, it is advisable to perform the test with the CM4 module NOT

MOUNTED.

Ochin CM4 carrier hardware tests v0.1 | 23 marzo 2022
2. Apply a reverse voltage between 7,5Vdc and 25Vdc on the power pad. The positive

pole is the one on the left and negative pole is on the right (top view).


Verify the “Zero Volt” present on the source of the SIA471DJ mosfet, placing the

multimeter across the C11 capacitor.

Test results

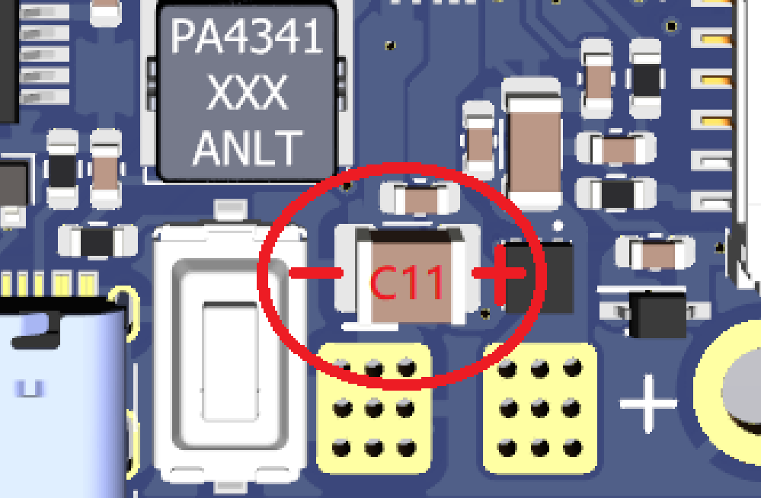
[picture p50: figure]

The test was performed numerous times on different boards and never presented any

problems.

Test Passed

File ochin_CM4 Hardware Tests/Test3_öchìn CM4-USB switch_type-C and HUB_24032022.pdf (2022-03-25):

Ochin CM4 carrier hardware tests v0.1 | 23 marzo 2022


## ochin_CM4 Hardware test number 3

## USB switch, type-C and HUB

Devices used for tests

1. ochin CM4 carrier board
2. Raspberry Pi CM4 module with eMMC
3. USB Type-C cable
4. Host PC
5. Power Supply 0-30Vdc

Test description

This test aims to verify the functionality of the USB switch. This device has the function

of switching the USB bus of the CM4 module, between the USB 2.0 4-ports hub and the

USB Type-C port.

The switch event appends by means of the VBUS coming from the USB Type-C port

when it is connected to a host computer. The switch event occurs only due to the VBUS

voltage, regardless of whether the CM4 module is in host or device mode.

Furthermore, the VBUS coming from the USB Type-C connector is used only to switch

the USB bus and not to power the board. This choice was made to avoid powering the

CM4 module and all the peripherals connected to it via the USB port, not being able to

supply the current required by the system to function.

Ochin CM4 carrier hardware tests v0.1 | 23 marzo 2022

Test execution

To test the switch to occurs, is possible to verify the functionality of the USB in both

ways, host mode and device mode:

Host Mode:

Power on the CM4 module and let the OS boot.

Once the OS is started, check the functionality of the four USB ports by

connecting an external device such as a usbstick.

To test that the USB hub is connected to the USB bus of the CM4 module, you

can perform a quick read and write test on the usbstick.

sudo mount /dev/sda1 /media/usb -o uid=pi,gid=pi

dd if=/media/usb/output.file of=/dev/zero bs=20M count=5 oflag=dsync

dd if=/dev/zero of=/media/usb/output.file bs=20M count=5 oflag=direct

Once the USB has been tested turn off the board.

Device Mode:

Hold down the S1 button first, then power on the board. When the CM4 module

is turned on with S1 pressed, it boots in device mode.

Connect the ochin board using a USB Type-C cable to the host and run the

“rpiboot” official application. If the USB switch is working fine, the PC should see

the CM4 as an USB drive.

NB: Even if the CM4 module is in host mode but the USB Type-C cable is connected to

a host computer, the 4 USB ports will not work, being disconnected from the USB bus

of the CM4 module. This happens because the VBUS coming from the host computer

drives the switch.

Test results

The test was performed numerous times on different boards and never presented any

problems.

Test Passed

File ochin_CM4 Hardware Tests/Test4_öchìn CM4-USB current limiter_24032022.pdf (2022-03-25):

Ochin CM4 carrier hardware tests v0.1 | 23 marzo 2022


## ochin_CM4 Hardware test number 4

## USB current limiter

Devices used for tests

1. ochin CM4 carrier board
2. Raspberry Pi CM4 module with eMMC
3. Power Supply 0-30Vdc
4. JST GHR-06V-S with AWG28 cables

Test description

This test is intended to verify the functionality of the AP22615 current limiter.

This device has the purpose of limiting the flow of current drawn by USB peripherals by

cutting the VBUS if the pre-set current threshold of 3A is exceeded.

Thanks to this device it is possible to guarantee the current necessary for the operation

of the CM4 module, even in the case of high absorption by a USB peripheral, following

a failure or malfunction.

To verify its operation, it is necessary to measure the VBUS and simultaneously increase

the drawn current, until the threshold is reached, when the VBUS voltage will drop due

to the opening of the switch.

Test execution

To increase the current over time, a programmable electronic load such as the DL24

must be connected to the VBUS. The DL24 allows you to set the current to be drawn

and can be increased to reach the threshold to verify the intervention of the AP22615.

The USB current threshold of the ochin_CM4 board is set to 3A, which is the maximum recommended threshold for the AP22615. However, this component can reach higher

currents, even if for short periods.

For this reason, in the ochin board used for the test, I decided to increase the threshold

to 4A to verify the operation even above the maximum recommended limit.

Test result

In the following plot it is possible to see the orange trace which represents the drawn

current. The blue trace represents the VBUS voltage measured on the pins of the USB

connectors present on the edge of the board.

As can be seen from the plot, as the drawn current increases, the voltage drop between

the Vin and the VBUS also increase and reaches 350mV when the drawn current hit 4A.

Once the 4A threshold is reached, the current limiter opens the circuit and the VBUS

goes to 0Vdc, to return to 5Vdc voltage when the load ceases.

In the plot there is a third gray trace, it represents the VBUS measured at the end of a

150mm long 28AWG wire (those that are normally connected to the GHR connectors).

As can be seen, the voltage drop in this case is much larger, reaching almost 900mV

with a drawn current of 4A.

This phenomenon is due to the small section of the conductor used and the length of

the wire. For this reason, in case of big loads on the USBs, it is always necessary to

choose a conductor of adequate size to avoid too high drop voltages.

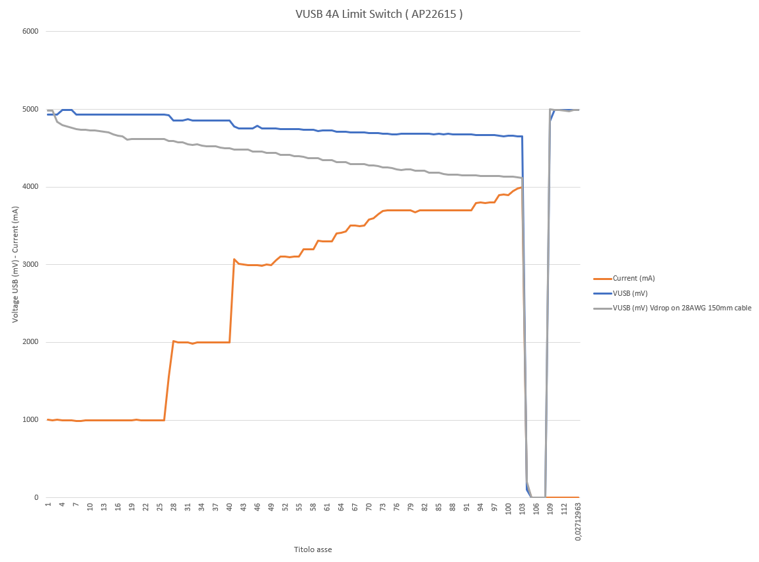
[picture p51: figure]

The test demonstrates the correct functioning of the current limiter, even at currents

higher than the recommended one of 3A.

Test Passed

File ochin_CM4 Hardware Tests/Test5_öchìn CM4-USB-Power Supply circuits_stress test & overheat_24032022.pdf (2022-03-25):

Ochin CM4 carrier hardware tests v0.1 | 23 marzo 2022


## ochin_CM4 Hardware test number 5

## Power Supply circuits:

## Stress test and overheat

Devices used for tests

1. ochin CM4 carrier board
2. Raspberry Pi CM4 module with eMMC
3. Power Supply 0-30Vdc
4. JST GHR-06V-S with AWG28 cables
5. DL24 electronic load

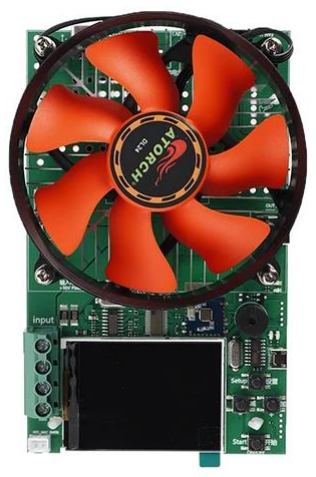
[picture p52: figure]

Test voltage : 2~200V
Working current: 0.2~20A
DL24 Discharge power: voltage*current < 180 W

Pico Scope 3000

4 analog channels

MSO models with 16 digital channels

200 MHz analog bandwidth

Up to 512 MS capture memory

1 GS/s real-time sampling

100 000 waveforms per second

Built-in arbitrary waveform generator

USB 3.0 connected and powered

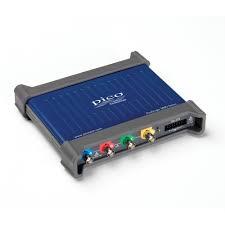
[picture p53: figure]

6. Thermal camera Fluke Ti9

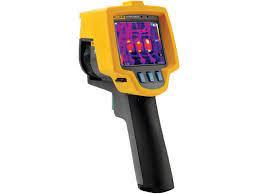
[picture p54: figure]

Sensor: 160x120

Temperature range: -20..250°C

Three-dimensional resolution: 2.5mrad

Thermal sensitivity (NETD): <=2@30°C

Test description

This test has the purpose of measuring the temperature of the ochin_CM4 board and of the CM4

module, of the components subjected to electrical stress. The temperature is measured by

means of a Fluke Ti9 thermal imager and its dedicated software, which allows you to perform

measurements in specific areas of the acquired thermal images.

The components whose temperature was measured are the following:

- Ochin_CM4 board
- U1 SIA471DJ - IC1 MAX20008
- L1 1uH
- IC4 AP22615AWU-7
- the PCB itself in the areas where the + 5V passes
- CM4 module
- CPU
- Power supply
- eMMC

- RAM
- BCM54210

The test lasts 4 hours during which the load increases every 20 minutes until the current reaches

the value of 3700mA. In addition to the current absorbed by the load, there is also the current

absorbed by the CM4 module in normal operating conditions (but not under stress) which was

not measured.

To increase the load over time, the test involves the insertion of an electronic load (DL24)

connected to the VBUS.

Test execution

To carry out this test, an electronic load was applied to the output of the switching regulator

mounted on the ochin board, at the edges of the capacitor C2. The electronic load DL24 was

used for this purpose.

To measure the temperature of the components subjected to electrical stress, a Fluke Ti9

thermal imaging camera was used. The images were sampled every 20 minutes, both on the top

side of the ochin_CM4 board and on the top side of the Raspberry Pi CM4 module.

The images taken by the thermal camera were elaborated by the Fluke software called “Smart

View”. By the means of this software was passible to measure the temperature of every

component subjected to heat. The “component temperature” calculated by the software is the

average of the temperatures measured by the camera sensor in the selected area.

Test result

In the following plot is possible to see the temperature of the components over time where the

yellow trace is the current being drawn by the electronic load connected to the .

To notice are the temperature of the switching regulator (MAX20008) and the current limiter

(AP22615) which reach the highest values, over 100 °C.

In the second plot is possible to see the temperature of some components mounted on the CM4

module.

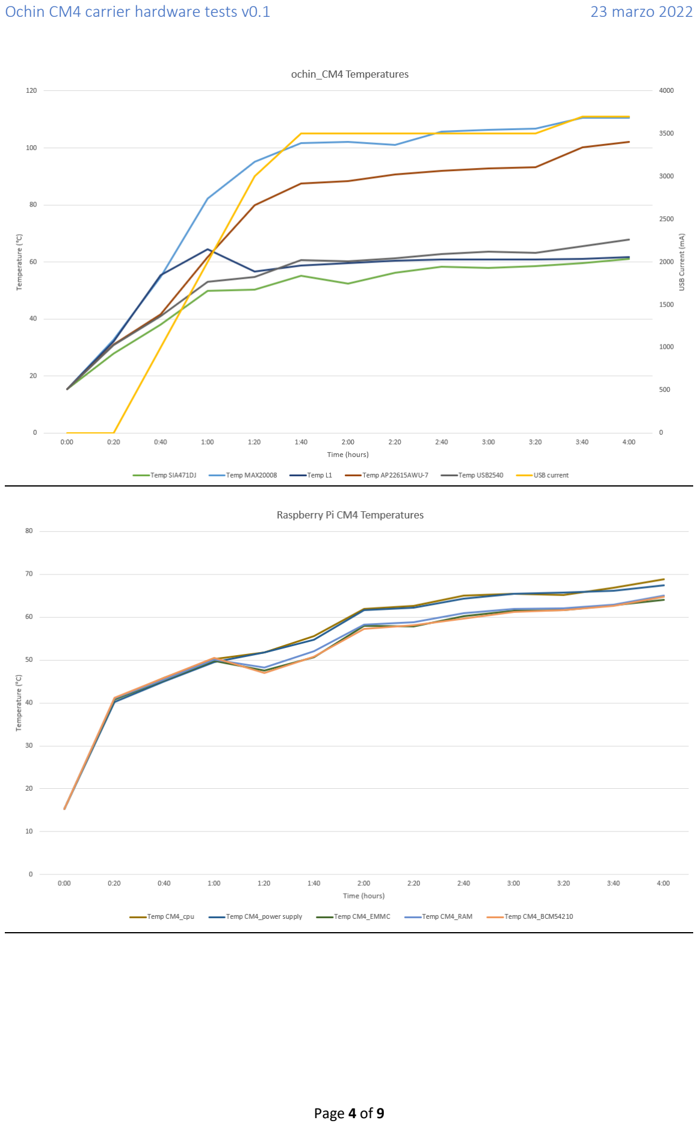
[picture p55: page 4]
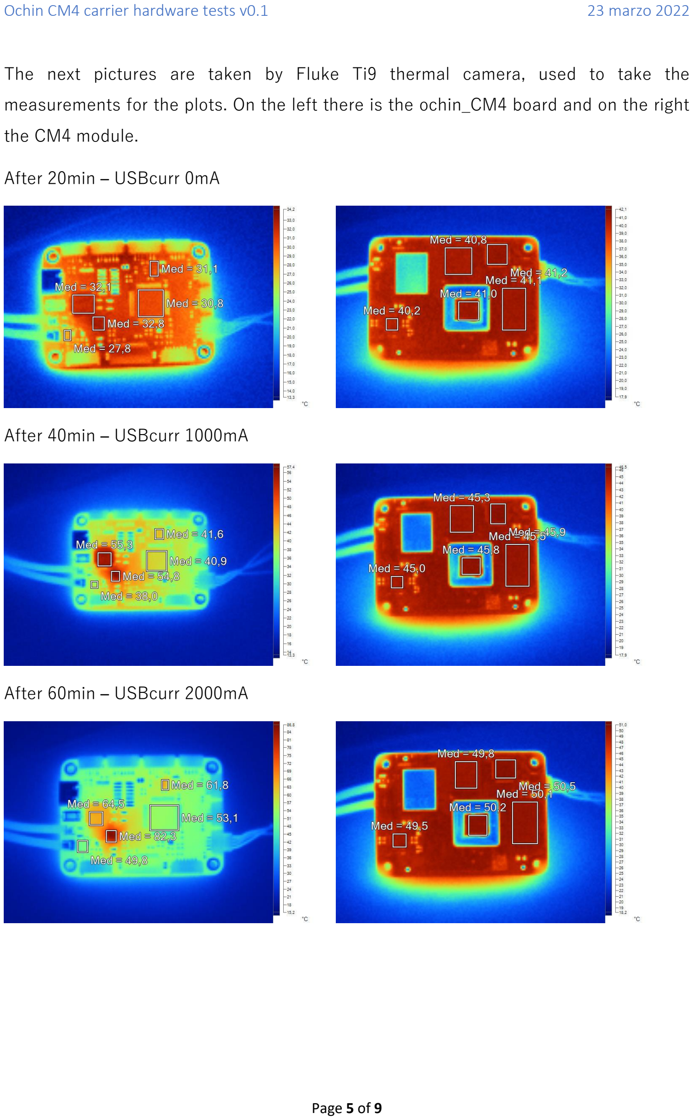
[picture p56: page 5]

The next pictures are taken by Fluke Ti9 thermal camera, used to take the

measurements for the plots. On the left there is the ochin_CM4 board and on the right

the CM4 module.

After 20min – USBcurr 0mA

After 40min – USBcurr 1000mA

After 60min – USBcurr 2000mA


After 80min – USBcurr 3000mA

After 100min – USBcurr 3500mA

After 120min – USBcurr 3500mA


After 140min – USBcurr 3500mA

After 160min – USBcurr 3500mA

After 180min – USBcurr 3500mA


After 200min – USBcurr 3500mA

After 220min – USBcurr 3700mA

After 240min – USBcurr 3700mA

Both boards reached quite high temperatures. However, the long duration of the test and the

non-negligible currents involved must be kept in mind. Furthermore, the test was carried out

indoors, without air circulation and without the use of a heat sink.

In normal use it is certainly advisable to use at least one passive heat sink for the Raspberry Pi

CM4 module.

If it’s planned to drawn a lot of current from the ochin_CM4 board via the USB ports or side

connectors, it is advisable to cool the MAX20008 and AP22615 as well.

Test Passed

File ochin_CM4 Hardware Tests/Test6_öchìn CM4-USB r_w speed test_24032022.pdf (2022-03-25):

Ochin CM4 carrier hardware tests v0.1 | 23 marzo 2022


## ochin_CM4 Hardware test number 4

## USBs r/w speed test

Devices used for tests

1. ochin CM4 carrier board
2. Raspberry Pi CM4 module with eMMC
3. Power Supply 0-30Vdc
4. Transcend Jetflash 760 USB3.0

Test description

This test is intended to measure the speed of USB 2.0 ports.

The test consists of writing or reading a certain amount of data on a USB disk by

measuring the time to read and the time to write. The test is carried out sequentially on

each of the 4 USB ports.

It should be noted that the reading and writing speed does not depend only on the CM4

module and the USB hub but also on the reading and writing speed of the USB disk.

These values should therefore not be considered as absolute values.

For the sake of the test, the /dev/zero source will be used since it’s a device file which generates a continuous stream of zeros. It could be also used as destination path, in which case it will accept ad discards all data written to it.

Test execution

The writing test is performed by means of the following “dd” command:

dd if=/dev/zero of=./speedTestFile bs=500M count=2 oflag=direct

The command will write 2 blocks of 500MBytes to ”/dev/zero”.

The reading test is performed by means of the following “dd” command:

dd if=./speedTestFile of=/dev/zero iflag=dsync

The “iflag=dsync” and “oflag=dsync" options set the synchronized I/O for data, this forces

a physical read/write of data on each operation (not using cache).

The USB memory stick used for the tests is a Transcend Jetflash 760 USB3.0 .

Test result

The following lines is the report of the read and write speed tests, made on each USB

2.0 port.

USB1 (sda1)

sudo mount /dev/sda1 /media/usb -o uid=pi,gid=pi

Write Test

dd if=/dev/zero of=/media/usb/output.file bs=500M count=2 oflag=dsync

1048576000 bytes (1.0 GB, 1000 MiB) copied, 40.7486 s, 25.7 MB/s

Read Test

dd if=/media/usb/output.file of=/dev/zero iflag=dsync

1048576000 bytes (1.0 GB, 1000 MiB) copied, 22.6864 s, 46.2 MB/s

USB2 (sdb1)

sudo mount /dev/sdb1 /media/usb -o uid=pi,gid=pi

Write Test

dd if=/dev/zero of=/media/usb/output.file bs=500M count=2 oflag=dsync

1048576000 bytes (1.0 GB, 1000 MiB) copied, 40.781 s, 25.7 MB/s

Read Test

dd if=/media/usb/output.file of=/dev/zero iflag=dsync

1048576000 bytes (1.0 GB, 1000 MiB) copied, 22.75 s, 46.1 MB/s

USB3 (sdc1)

sudo mount /dev/sdc1 /media/usb -o uid=pi,gid=pi

Write Test

dd if=/dev/zero of=/media/usb/output.file bs=500M count=2 oflag=dsync

1048576000 bytes (1.0 GB, 1000 MiB) copied, 40.4118 s, 25.9 MB/s

Read Test

dd if=/media/usb/output.file of=/dev/zero iflag=dsync

1048576000 bytes (1.0 GB, 1000 MiB) copied, 21.9964 s, 47.7 MB/s

USB4 (sdd1)

sudo mount /dev/sdd1 /media/usb -o uid=pi,gid=pi

Write Test

dd if=/dev/zero of=/media/usb/output.file bs=500M count=2 oflag=dsync

1048576000 bytes (1.0 GB, 1000 MiB) copied, 45.5359 s, 23.0 MB/s

Read Test

dd if=/media/usb/output.file of=/dev/zero iflag=dsync

1048576000 bytes (1.0 GB, 1000 MiB) copied, 21.748 s, 48.2 MB/s

From the results of the tests carried out, it can be seen that speeds around 23MB /

sec in writing and 48MB / sec in reading are reached. Keep in mind that the purpose of

the test is not to measure the speed of the USB device, but the maximum speed

reached by the USB bus. We can therefore refer to the speed reached during the

reading. The reading operation, for reasons related to the architecture of solid state

memories, is less complicated than writing and therefore generally reaches higher

speeds. In these tests the reading speed is very close to the theoretical maximum

speed of the USB2.0 bus, so we can say that the system is working at full speed.

Test Passed

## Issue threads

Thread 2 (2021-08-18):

first groupbuy for ochin board - declaration of interest

pernicious-flier, 2021-08-18:
To start the production of the first batch of the ochin board is important to set the number of the boards to produce, in order to keep the price low. Please comment let me know if you're interested to buy one or more ochin boards. The price will be known when we reach a sufficient number of interest declaration. THIS IS WITHOUT ANY OBBLIGATION for anybody.
Please consider the chip shortage too, the production date depends also on the availability of materials.
But i think we will do it!

careyer, 2021-08-18:
Thanks! Count me in :-)

Dronotique, 2021-08-18:
You can count me also, for 2 or 3 boards depending of the price

lordmrc, 2021-08-18:
I'm in for 1-2 boards, as well!

zingaros, 2021-08-18:
I'm in for 1 too. Well done!!!!

L1Blom, 2021-08-18:
Count me in

FastJack2, 2021-08-18:
Depending on the price, i would take one or two

psfleming, 2021-08-19:
I'm in, have a IMX477 I would like to use.

patemil, 2021-08-19:
I’m also interested in 1 or 2 cards depending on price

Solhead, 2021-08-19:
Add two.

davidbitton, 2021-08-20:
I'll be good for two.

ArthurFDLR, 2021-08-22:
Count me in for one

cyberjunkiefr, 2021-08-31:
I'm also interested. Good job

careyer, 2021-09-03:
counting 22 as of now. Any threshold that we have to reach to kickoff the first batch?

pernicious-flier, 2021-09-03:
>
>
> counting 22 as of now. Any threshold that we have to reach to kickoff the first batch?
Hello Careyer, I would start with 100 boards min. From the beginning of the campaign we have 4 weeks to reach the threshold, otherwise the campaign will fail, but i don't think it will be a problem...  the biggest problem at the moment is the availability of the components .. it is incredible but if you take a ride on mouser, rs-components or digikey it is practically everything backordered and the warehouses are empty.... sorry to keep you waiting but the chip shortage it's a global problem, i'm trying to do it as soon as possible. In the meantime i will update you with more test.

pernicious-flier, 2021-09-03:
Some of you asked to have one of the prototype but unfortunately is not possible. This is because costed a lot (and you don't wanna pay that mutch)  and i only have few units. I decided to give a couple to peoples that have some visibility on youtube to make video and gain popularity, hopefully we'll have more people interested.

nettleand, 2021-09-03:
2 boards for me when manufacturing gets started. Thanks

davidbitton, 2021-09-03:
> counting 22 as of now. Any threshold that we have to reach to kickoff the first batch?

22 people or 22 boards?

pernicious-flier, 2021-09-03:
> > counting 22 as of now. Any threshold that we have to reach to kickoff the first batch?
>
> 22 people or 22 boards?

22 boards here plus 5 or 6 via private msgs

14roiron, 2021-09-05:
I'm also interested. Good job

mathewcommons, 2021-09-06:
Interested in 2

JoseFPV7, 2021-09-06:
Interested in 2 boards, let me ask some friends

chrisclw, 2021-09-10:
I would be interested in 2 boards as well.

Mateio, 2021-09-15:
Same for me. 1 maybe 2.

MacDaddyFPV, 2021-09-21:
I would be interested in 1 board. Thanks.

chrisclw, 2021-10-02:
I would be interested in 1 or 2 boards.

white-rabbitGR, 2021-10-02:
I will buy 2 boards. Count me in!

dan0412, 2021-10-02:
I would be interested in 1 board. Thanks.

nettleand, 2021-10-23:
Hi Flavio, how are the numbers coming along? Are we any closer to getting a production run going yet?  Just watched Curry Kittens intro YouTube video.  Excited to get my hands on an ochin board soon!! Cheers

dynoprilia, 2021-10-31:
I'm in for a couple of boards please price dependant.
Regards
Dean

FastJack2, 2021-11-02:
> Can i fly eg. 40km out with Ochin CM4 ?

as the range is board-independent and just related to wifi cards and antennas: sure, if your wifi card/antenna setup is sufficient

hseduster, 2021-12-03:
Hopefully this is still going strong. Just saw CurryKitten on YT with this and now I gotta have one! Actually I'd like two...

So I'm down for two, at least.

pernicious-flier, 2021-12-03:
Hello everyone, I'm sorry not to have updated you anymore but unfortunately things did not go as I hoped .. due to the chip shortage it is practically impossible to find the components to produce ochin boards from official distributors (we are talking about deliveries in 2023 ..). When I found the components from "alternative" distributors, the prices have risen shamefully, for example the USB2514 (usb hub), the cost before the shortage was 3$/pc on mouser, now those who have some chip in stock, sell them at 20$/pc, moreover they don't are reliable and I'm not sure how they stored the chips, as long as they really have them ...
But I'm not the type of guy who give up easily .. so I completely redesigned the board (even though it worked perfectly) selecting components that are currently widely available on the market. The layout of the connectors and the functionalities have remained the same and I have also made some improvements. For example I have improved the power supply that is now able to deliver up to 8A of which 4A to the USBs (you can power anything;) almost). At the moment I'm waiting for the new prototypes to arrive, as soon as they arrive I test them and then we start with the first batch! I keep you updated and hopefully someone doesn't buy all the chips !!

cyberjunkiefr, 2021-12-03:
Thanks for the great job!

careyer, 2021-12-03:
Yeah! Thank you for all your effort! Lets hurry up before the chips are all gone

Von meinem iPhone gesendet

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

hseduster, 2021-12-03:
Shoot...
If it comes down to a make or break, I'd be down for 3 or 4. Really wanting to see this come to fruition! Seems so promising!

adalta87, 2021-12-06:
I would be down for 2 board as well, great little project and very sorry to hear about all the shortages! glad you have redesigned such a great project.

praveen-khm, 2021-12-09:
If well priced,  I would pickup 4 units.

hseduster, 2021-12-14:
I know it would vary a lot, but is there any chance we could get a rough price? I mean something as vague as "under $100" or "between 100 and 300" would be fine by me. Even at something like 200, I would want at least 2-4 boards. I'd love to commit to more (much more...) but I don't wanna take out a second mortgage...

Just a thought anyway. Either way, I want to see this thing on my desk like yesterday!

adalta87, 2021-12-14:
Oh in that case I will take 4 modules!!

On Tue, Dec 14, 2021 at 2:42 PM pernicious-flier ***@***.***>
wrote:

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

hseduster, 2021-12-18:
I too would be in for at least 4 given a $100 price tag!

robert-b, 2022-01-06:
i also would take a couple of boards ... 3

careyer, 2022-01-06:
Just wondering... which variety of the CM4 Module (with EMMc memory, with MictoSD card, with or without WiFi, with 2,4,8 GB RSM is presumably the best bet?
Thanks!

pernicious-flier, 2022-01-07:
> Just wondering... which variety of the CM4 Module (with EMMc memory, with MictoSD card, with or without WiFi, with 2,4,8 GB RSM is presumably the best bet? Thanks!
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
pernicious-flier, 2022-03-18:
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

You mean the power cables? Nope, has two pads like the ones you find on the flight controller. The pads are one each layer connected with several vias, are strong once soldered.

MorrisR2, 2022-03-18:
FYI it's a 2 amp board. That means a quality Dupont plug ("servo connector") would be an appropriate power connector.

An XT60 would be killing a fly with a bazooka.

davidbitton, 2022-03-18:
@MorrisR2 I was just going off the wire gauge used in the product pictures.

riox87, 2022-03-22:
Count me in for at least 1 board - maybe 2 if the price is right! :)

dynoprilia, 2022-03-22:
Awesome news 👏 Get Outlook for Android

Awsmits, 2022-04-15:
Count me in for one board, thanks.

FelixvdDonk, 2022-04-23:
Also interested in 2 boards

Mateio, 2022-05-31:
Great news @pernicious-flier. Can’t wait to place an order. As an aside : it would be very nice if seeed was to sell a package of CM4 + Ochin board.

pernicious-flier, 2022-05-31:
> Great news @pernicious-flier. Can’t wait to place an order. As an aside : it would be very nice if seeed was to sell a package of CM4 + Ochin board.

Yes i know.. they also sell CM4, the problem is the shortage of chips.. i suggest you to subscribe, the will tell you when the item is back in stock

FastJack2, 2022-06-06:
> Hello guys, the ochin boards are under production! 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
>
> You may also be interested on my Raspberry Pi based framework https://github.com/ochin-space/ochin_web A lot of apps for drones and planes are yet to come! Please let me know what you think!

Is there a website where the production status can be seen? E.g. an regularly updated version of the image you posted? Clearly don't wanna miss the first batch 😂😉

pernicious-flier, 2022-06-06:
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

Hi FastJack2, unfortunately isn't possible, it's just my personal account. Don't worry, i will let you know a little earlier

pernicious-flier, 2022-06-06:
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
PCB are finished and the components should be there, i bought them months ago

pernicious-flier, 2022-06-06:
> 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 PCB are finished and the components should be there, i bought them months ago

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
PCB are finished and the components should be there, i bought them months ago

shurra, 2022-06-10:
+2 boards

ZibOk-fpv, 2022-06-14:
Add 2 for me and my dog:)

pernicious-flier, 2022-06-14:
> How much $ will it be listed for?
> […](#)
> On Jun 14, 2022, at 9:28 AM, ZibOk-fpv ***@***.***> wrote:   Add 2 for me and my dog:) — Reply to this email directly, view it on GitHub, or unsubscribe. You are receiving this because you commented.

Don't know yet exaclty, but will be around 60/70$, not cheap i know but it's a very small production sorry

stuartcol, 2022-06-30:
I’m interested in a couple of boards

WhiteCarcosa, 2022-07-31:
1 for me thanks

pernicious-flier, 2022-08-26:
**Hi Guys, we finally did it !!**
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

The boards were all tested one by one to verify the operation of the CSI camera, USB ports, UARTS etc. On a sample basis, some boards were also tested with OpenHD.
The boards will be distributed by Seeedstudio through their channels (seeedstudio Marketplace, Mouser, DigiKey and more).
We kept the price as low as possible, I said between 60$ and 70$ and it's set at 59.90$ including shipping.
Yahoooo!

https://www.seeedstudio.com/ochin-tiny-carrier-board-raspberry-pi-compute-module-4-p-5463.html

stuartcol, 2022-08-26:
My orders in

👍

Regards

Stuart

On 26 Aug 2022, at 6:21 pm, perniciousflier ***@***.***> wrote:

Hi Guys, we finally did it !!
[Immagine 2022-08-26 101730]<https://user-images.githubusercontent.com/48369900/186856545-1f74c8ee-1f48-4150-bbe1-b68700fd4e09.jpg>

The boards were all tested one by one to verify the operation of the CSI camera, USB ports, UARTS etc. On a sample basis, some boards were also tested with OpenHD.
The boards will be distributed by Seeedstudio through their channels (seeedstudio Marketplace, Mouser, DigiKey and more).
We kept the price as low as possible, I said between 60$ and 70$ and it's set at 59.90$ including shipping.
Yahoooo!

https://www.seeedstudio.com/ochin-tiny-carrier-board-raspberry-pi-compute-module-4-p-5463.html

—
Reply to this email directly, view it on GitHub<https://github.com/ochin-space/ochin-CM4/issues/2#issuecomment-1228203112>, or unsubscribe<https://github.com/notifications/unsubscribe-auth/AJ6HCC2E7PSDAEC4PYLOBMLV3B5ADANCNFSM5CLRO5CQ>.
You are receiving this because you commented.Message ID: ***@***.***>

FastJack2, 2022-08-26:
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

Ordered 2!
Absolutely great work!
Thank you!

davidbitton, 2022-08-26:
Ordered! Thanks.

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
--
Sent from
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

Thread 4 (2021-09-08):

Board files available?

WARGRaph, 2021-09-08:
Hi,

I want to try the carrier board as quickly as possible and don't care about the price much. Would you share the board files with me so I can order prototypes myself or do you see another way?

Kind Regards
Raphael

pernicious-flier, 2021-09-21:
Hello Raphael, sorry i'm not gonna share the board files for now.
Best regards, Flavio

Closed 2021-09-21.

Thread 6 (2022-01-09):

which variety of the CM4 Module

pernicious-flier, 2022-01-09:
> > Just wondering... which variety of the CM4 Module (with EMMc memory, with MictoSD card, with or without WiFi, with 2,4,8 GB RSM is presumably the best bet? Thanks!
>
> Hello Careyer, EMMc is mandatory, ochin board doesn't have the sdcard header. The reasons why are: save space for other connectors (i wanted to keep the same size of the cm4), emmc is much faster and durable, the interface is used for emmc OR sdcard (cm4 with EMMc doesn't work with sdcard). If you want to use OpenHD 16GB are enought (maybe 8GB but not sure). I'm also developing a sw, totally different in goal and type from OpenHD and it may need more space, i'll tell you more very soon. About the RAM, OpenHD guys say that 1GB is enought, with other sw you may need more, depends on what you want to do, for example for computer vision, machine learning etc, more is better. In my opinion 16GB EMMc 2GB RAM is a good option, but if you want to develop sw you better go to 32GB.

Thank you! Shall i take a variety with WIFI+BT or without? I mean ... will it interfere when using external Wifi adapters?

_Originally posted by @careyer in https://github.com/ochin-space/ochin-CM4/issues/2#issuecomment-1008350833_

Closed 2022-01-09.

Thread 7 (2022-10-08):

Open hardware design files

samuk, 2022-10-08:
I see you use the open hardware logo, but I don't see the hardware files Kicad etc are they in a separate repo?

pernicious-flier, 2022-10-11:
>

Hello samuk, i've already explained in other places the reason why i didn't share the kicad files, I'll explain it again once and for all.
The reason lies in the fact that the production of a single piece does not make any sense due to the very high production and assembly costs. It is also not the type of board that can be assembled by hand in a hobbyist workshop. It is in fact required the assembly of components that are difficult to handle and weld, delicate and for which a high positioning accuracy is also required (an example for all is the positioning of the mezzanines).
For those wishing to understand and learn about my project, the schematics are available in this repo and at the end of the manual there are the images of the 4-layer pcb.
Making the kicad files and therefore the gerber files available, means nothing for those who are really interested in the project, as I said it is much more expensive to build it than to buy it, and the only way to lower costs is to produce as many boards as possible, but this it is a self-financed project.
Gerbers could be of interest to those who have the opportunity to produce a big number of ochin_CM4 boards without initial investment, hours and hours of design, document, tests, debug, prototypes and marketing ... in short, only profits without work and risks. Probably this would allow, initially, to lower the price by a few euros, but it would kill this project forever and I don't want that to happen.
On the contrary, I would like to continue with the development, listening to your needs and talking with the developers of other beautiful open projects such as OpenHD in order to improve the board.
By the way, the Raspberry Pi provides the kicad sources of the IO board, which includes what is contained in the ochin and much more. In the ochin_CM4 board I used slightly different components and the power section it is completely different, but theoretically they are very similar.
If anyone has technical questions that I can answer, I will be happy to do so.
Hope you can understand, Flavio

samuk, 2022-10-11:
Hi Flavio

That's fine, it makes sense.

My only issue is with your use of the Open hardware logo & branding. https://www.oshwa.org/open-source-hardware-logo/ Your board does not meet the open hardware definition. If you removed those from your board design it would be clear to everyone that this is not an open hardware product.

You might find you have to explain it less often then.

pernicious-flier, 2022-10-11:
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

You're right samuk, my fault. I thought it was enough to provide the documentation but the license is very clear about the sources. I will remove the logo from the design.
Thanks, Flavio

samuk, 2022-10-11:
No worries, I don't mean to be a dick about it. It does look like a nice board..

pernicious-flier, 2022-10-11:
Ha ha, no worries, it's  good advice!

pernicious-flier, 2022-10-11:
OSHW logo removed,
but I want to write to the Oshw guys because in my opinion my motivations are solid. My project contains all the information to understand and possibly replicate the board, more information than is normally found in other oshw projects (manuals, description of the hw tests carried out, wiring tips etc ..). Therefore, in my opinion, the dissemination function is fully fulfilled. The sources are missing for the reasons I explained, mainly to protect the project (which the oshw license does not do). I think they should create another level of license, which requires the complete description of the electronics without sharing the sources. Obviously this problem does not exist for open source software, which does not require production costs.
What do you think Samuk?

samuk, 2022-10-11:
I'm not an expert. The boards I've been involved with have all been released under an open hardware licence: https://github.com/rosmo-robot/

My interest in your board was as a carrier for https://github.com/antmicro/arvsom this would have fitted in with the 'Open hardware' brand of Rosmo. I might have made a few minor alterations to your board: An extra Qwiic socket and perhaps a 5pin breakout garden I2C. I don't want to, nor have the skills to re-engineer the whole thing from scratch. So for my (particular) interest, your board is no longer helpful to me. No matter how good the documentation. I'll probably use something like https://github.com/samuk/CM4-Header-Gigabit-2xCam instead.

pernicious-flier, 2022-10-11:
> I'm not an expert. The boards I've been involved with have all been released under an open hardware licence: https://github.com/rosmo-robot/
>
> My interest in your board was as a carrier for https://github.com/antmicro/arvsom this would have fitted in with the 'Open hardware' brand of Rosmo. I might have made a few minor alterations to your board: An extra Qwiic socket and perhaps a 5pin breakout garden I2C. I don't want to, nor have the skills to re-engineer the whole thing from scratch. So for my (particular) interest, your board is no longer helpful to me. No matter how good the documentation. I'll probably use something like https://github.com/samuk/CM4-Header-Gigabit-2xCam instead.

I get it, but trust me that modifying the board means redoing part or all of the layout, which is the tricky part. If you don't know how to deal with fast signals, track impedance, differential pairs, and ground planes, nothing will work. I encourage you to delve into these topics before modifying such a card.
Greetings, Flavio

Closed 2022-10-11.

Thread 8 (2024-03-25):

Anyway to get the Gerber and BOM?

villivateur, 2024-03-25:
Hello, it is hard to buy board from seeedstudio or any other provider in my country. But I really want to use this board.

Luckily, it is very cheap for me to make a PCB, and I have all the tools to do SMT. So, can I get the Gerber and BOM file? If so, I can make the board myself. I do not need the hardware source file at all, but only the production file.

raphaelscholle, 2024-07-30:
The gpl licence is for the files in this github, meaning documentation and such. You do not need to make everyting opensource if you don't want to. The actual hardware is closed source. That's also not unusual, since often NDA'S and such things are required to make Hardware.

Nowhere is stated that this is an opensource hardware project. But sure, try to get any mobile phone manufacturer to release their hardware open source, since it use opensource software.

richard-scott, 2024-07-30:
@raphaelscholle, you are on the right track, as the GPL covers all the files in the Github Repo.

The fact that it is distributed with a GPL license means it is Open Source. **Anything** in the Repo needs to have source files available to allow modification. If the project wants to restrict elements of the distribution then the GPL is not the license for the project.

And no, I would not expect a mobile phone manufacturer to release their hardware as open source. However, I doubt you'd find their schematics online in a repo on GitHub covered by a GPL license.

In the GPL it states the following:

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

So, that defines "source code" as the files required to make modifications, and object code is another output generated by the source code files. PCB Schematics in PDF format are "Object code", as these can't be modified without having the preferred format source files.

A bit further down, it also defines what you need to provide for Object code:

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

So, in this Repo (and [this](https://github.com/ochin-space/ochin-CM4v2) one), the Source code files for your Object code are the KiCad project files. [Other](https://github.com/TwentyTwoHW/portal-hardware) Open Source Hardware projects distributed under GPL provide these files.

pernicious-flier, 2024-07-31:
> Hello, it is hard to buy board from seeedstudio or any other provider in my country. But I really want to use this board.
>
> Luckily, it is very cheap for me to make a PCB, and I have all the tools to do SMT. So, can I get the Gerber and BOM file? If so, I can make the board myself. I do not need the hardware source file at all, but only the production file.

I thank you Villivateur for your opinion about the project, I am glad you like it. It was out of stock for a while because it was in testing/production v2 which has many more features and now it is available in stock.
To answer your question, unfortunately, no, I do not release design sources.

pernicious-flier, 2024-07-31:
Thanks for the discussion guys, now it takes a lawyer even to post on github :)
Anyway I clarified everything about the license of this repo and that of the ochin_cm4v2 in the README.md, I hope everything is clear now.
Have fun with the ochin! Best, Fla

Closed 2024-07-31.

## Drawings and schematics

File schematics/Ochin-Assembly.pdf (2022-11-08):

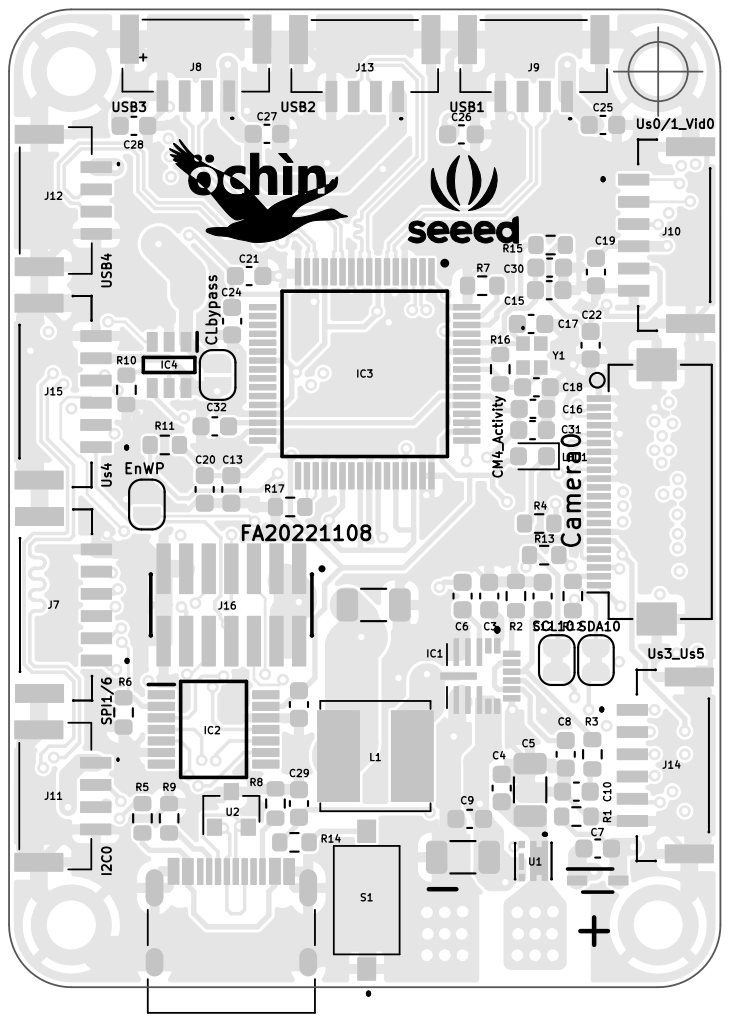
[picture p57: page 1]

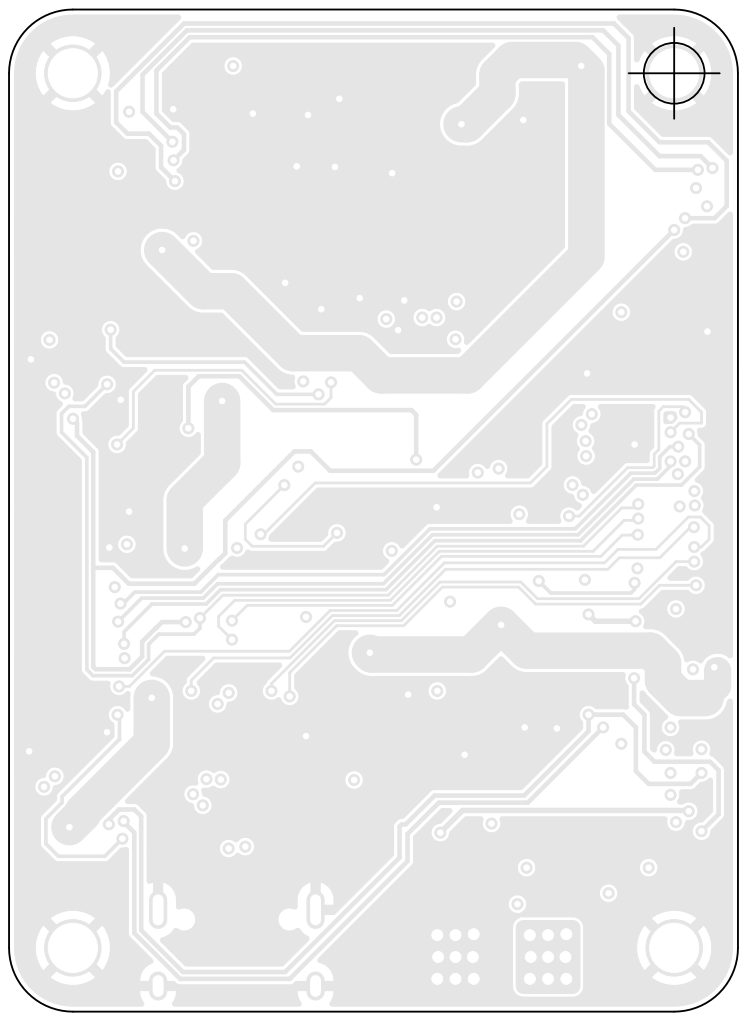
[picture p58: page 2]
D Date: 2022-05-11 KiCad E.D.A. kicad (6.99.0) Size: A5; Rev:; Id: 1/1 Title: ochin_CM4; File: Ochin.kicad_pcb; Sheet: Assembly

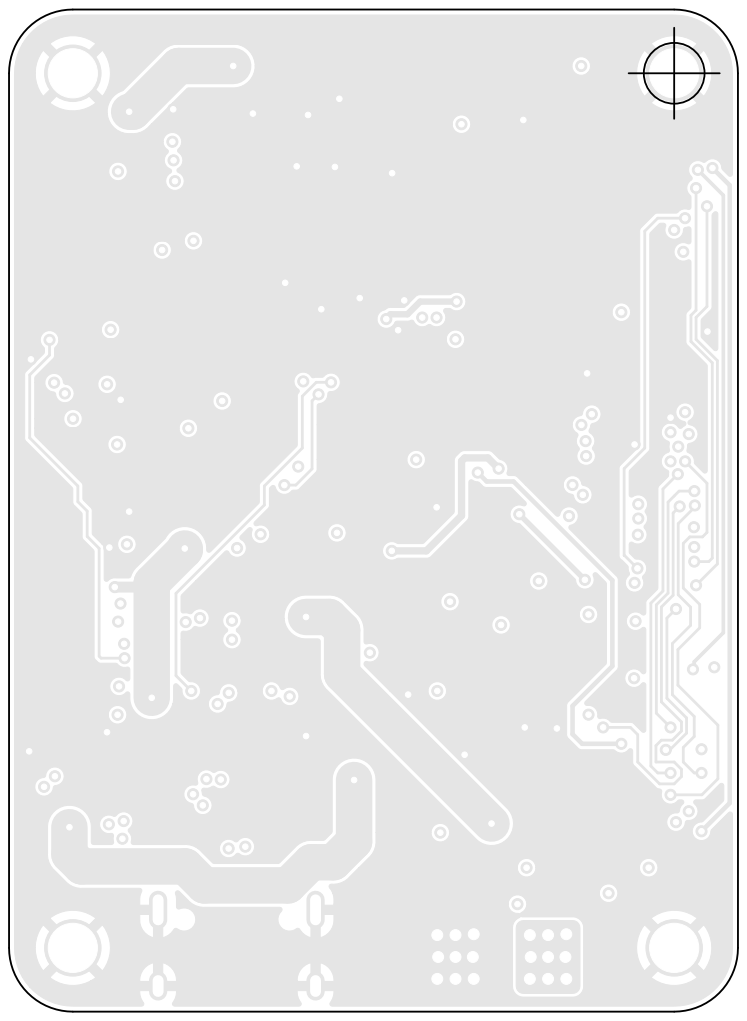
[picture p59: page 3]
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

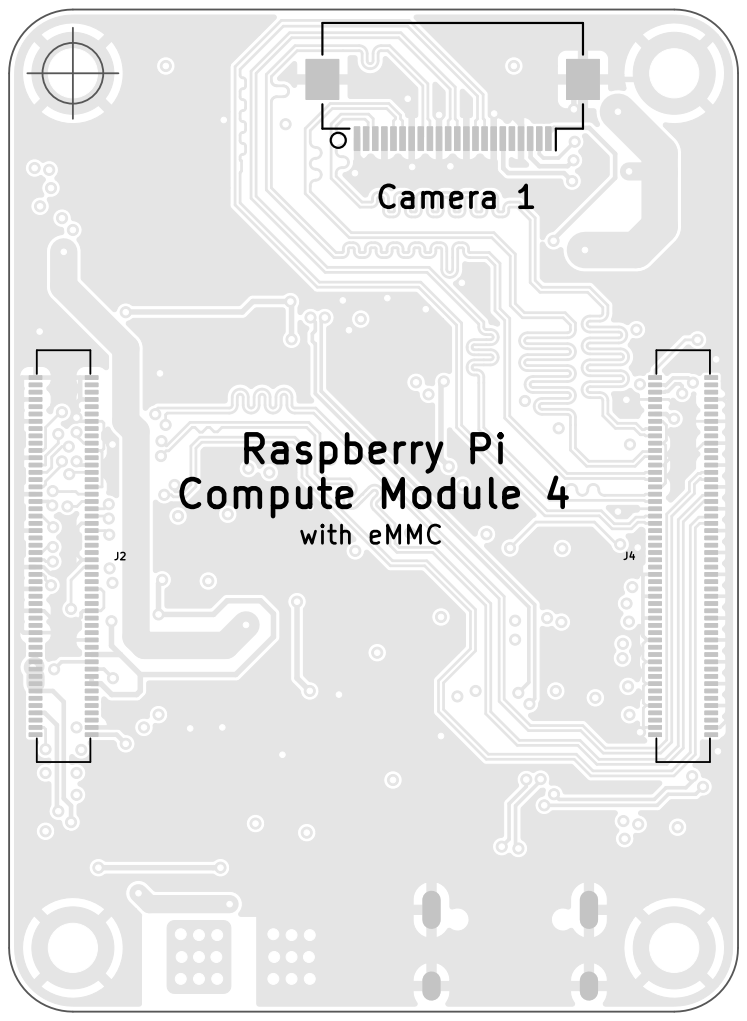
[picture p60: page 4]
Raspberry Pi Compute Module 4; D Date: 2022-05-11 KiCad E.D.A. kicad (6.99.0) Size: A5; Rev:; Id: 1/1 Title: ochin_CM4; File: Ochin.kicad_pcb; Sheet: Assembly

with eMMC Camera 1

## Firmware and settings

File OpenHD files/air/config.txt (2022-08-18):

# General note: You can find more info on the options in this file here:
# https://www.raspberrypi.org/documentation/configuration/config-txt.md

# uncomment if you get no picture on HDMI for a default "safe" mode
#hdmi_safe=1

# uncomment this if your display has a black border of unused pixels visible
# and your display can output without overscan
disable_overscan=1

# uncomment if hdmi display is not detected and composite is being output
# also set this in conjunction with a specific HDMI mode below if you want
# to connect your display when the Raspberry is already running, i.e. the
# display has not been connected during power-up
#
#hdmi_force_hotplug=1

# uncomment to force a specific HDMI mode
#
# 640x480
#hdmi_group=1
#hdmi_mode=1
#
# 800x600 Fatshark HD1/2/3 (4:3)
#hdmi_group=2
#hdmi_mode=9
#
# 1024x768
#hdmi_group=2
#hdmi_mode=16
#
# 1280x720 Fatshark Base HD
#hdmi_group=1
#hdmi_mode=4
#
# 1280x800 Headplay HD
#hdmi_group=2
#hdmi_mode=28
#
# 1280x1024
#hdmi_group=2
#hdmi_mode=35
#
# 1440x900
#hdmi_group=2
#hdmi_mode=47
#
# 1680x1050
#hdmi_group=2
#hdmi_mode=58
#
# 1920x1080 Goggles One/Two
#hdmi_group=1
#hdmi_mode=16

# Topfoison 6" 1080x1920 display
#hdmi_ignore_edid=0xa5000080
#max_framebuffer_width=1080
#max_framebuffer_height=1920
#display_rotate=3
#hdmi_timings=1080 0 118 4 118 1920 0 4 4 3 0 0 0 60 0 152940000 3
#hdmi_group=2
#hdmi_mode=87

# OSVR HDK 1.4
#[EDID=SVR-OSVR_HDK]
#hdmi_ignore_edid=0xa5000080
#hdmi_group=2
#hdmi_mode=87
#hdmi_timings=1080 0 32 5 11 1920 0 12 5 6 0 0 0 60 0 131000000 3
#display_rotate=3
#max_framebuffer_width=1080
#max_framebuffer_height=1920
max_framebuffers=2

# uncomment to increase signal to HDMI, if you have interference,
# blanking, or no display
#config_hdmi_boost=4

# uncomment for composite PAL
#sdtv_mode=2

# Enable audio (loads snd_bcm2835)
dtparam=audio=on

gpu_mem=160

# force gpu to run in turbo mode for less latency and jitter
#force_turbo=1

# prevent throttling on undervoltage, but still allow throttling on overtemp
avoid_warnings=2

# Set higher voltage for stability
over_voltage=3

# overclock CORE/GPU/SDRAM for less latency and higher data troughput
#gpu_freq=400
#sdram_freq=433

# speed-up booting
bootcode_delay=0
boot_delay=0
disable_splash=1

# allow for maximum 1.2A current on USB bus
#max_usb_current=1

# disable Bluetooth on Pi3 so that the GPIO serial port is usable
dtoverlay=pi3-disable-bt

# needed for serial port, otherwise /dev/AMA0 does not exist
enable_uart=1

# reduce maximum USB hub depth to 2
usb_mdio=0x7000

# test, don't change
#hvs_priority=0x32ff
#
# uncomment for I2C
#dtparam=i2c1=on
dtparam=i2c_arm=on
#uncomment below if using veye innomaker imx219 cam or HAT
#dtparam=i2c_vc=on
#
# uncomment for SPI
#dtparam=spi=on

start_x=1

[pi0]
start_file=zero_x.elf
fixup_file=zeroup_x.dat
[pi0w]
start_file=zero_x.elf
fixup_file=zeroup_x.dat

[pi1]
start_file=1to3b_x.elf
fixup_file=1to3bup_x.dat
[pi2]
start_file=1to3b_x.elf
fixup_file=1to3bup_x.dat
[pi3]
start_file=1to3b_x.elf
fixup_file=1to3bup_x.dat
[pi3+]
start_file=start_x.elf
fixup_file=fixup_x.dat

[all]
dtoverlay=vc4-fkms-v3d

#USB enable
dtoverlay=dwc2,dr_mode=host

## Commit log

2021-08-16 added manuals and images
    [ochin_CM4-Ochin.stl]
2021-09-21 Added 3d models for mount the ochin_CM4 board and IMX219 camera. Added OpenHD config files for ochin_CM4.
    [EasyStar_camera_mount.FCStd, EasyStar_camera_mount_bridge.stl, EasyStar_camera_mount_cap.stl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]
2021-10-09 updated the top image of the board (rotated the usb wire names)
2022-02-05 The ochin_CM4 board has been redesigned with different components due to the unavailability of those present in the first version (due to the chip shortage). The big differences are as follows: - rep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
    [config.txt]
2022-03-25 Schematic and manual updated to the last version. Added "ochin_CM4 Hardware Tests" files and folder. ochin_CM4 3d model updated. Added 3d printable cover files.
    [config.txt, ochin_CM4-Ochin.stl, ochin_CM4.stl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]
2022-03-28 updated the pcb stackup
2022-05-11 Updated documents and schematic to the latest version
    [config.txt, ochin_mount-botCover.stl, ochin_mount-topCover.stl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]
2022-05-11 updated board image with horizontal USB signal sequence
2022-05-11 added the STL of the mounted boards with 3d printed top and bot covers
2022-05-11 updated öchìn CM4 - Wiring and Suggestions
2022-07-03 3d model updated
    [ochin_mount-turret.stl, ochin_mount.FCStd]
2022-07-04 updated 3d mounts
    [ochin_mount-botCover.stl, ochin_mount-topCover.stl, ochin_mount-turret.stl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]
2022-07-05 updated turret size (for 0,5mm CPU thermal pad )
    [ochin_mount-turret.stl, ochin_mount.FCStd]
2022-08-03 updated wiring and suggestion added the extractor tool added seeedstudio test report
    [ochin_mount-botCover.stl, ochin_mount-extractor.stl, ochin_mount-topCover.stl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]
2022-08-03 updated USB and CSI tests updated device tree
2022-08-17 updated OpenHD config files
    [config.txt, osdconfig.txt]
2022-08-18 updated the openhd config files
    [config.txt]
2022-09-01 updated wiring and suggestions and added 3d files for microaservo gimbal
    [camera_gimbal.FCStd, camera_gimbal_assembly.FCStd, camera_gimbal_pan-PAN.stl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]
2022-11-08 renamed I2C1 to I2C0 added ochin step file updated manuals
2022-11-08 updated docs for the second batch changes (I2C0 jumpers NC, silkscreen)
